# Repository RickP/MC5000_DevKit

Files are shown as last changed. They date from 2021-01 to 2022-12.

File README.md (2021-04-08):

# MC5000_DevKit

A development board that brings the [Shenzhen IO game](https://www.zachtronics.com/shenzhen-io/) to real hardware.

This documentation is intended for people who want to build/extend/bugfix the hardware. 

If you have an MC5000 DevKit board and want to play with it go to the [user documentation](https://rickp.github.io/MC5000_DevKit/).

**I'm planning to order some ready-to-use boards if there are enough people interested. Drop me a message (pannen at gmail dot com) if you're interested in getting one or more**

## Overview

The project consists of three parts. The firmware for the PFS173 microcontroller used in this project, a circuit board that connects to a computer via USB and a cross-platform desktop application that is used to programm the board.

The main use of this is to teach beginners the basics of programming and electronics by solving problems with increasing difficulty. Users have to make electric connection on the circuit board with jumper cable and programm the two microcontrollers with a simplified assembler language to solve the tasks.

## The circuit board

Cuircuit board picture MC5000 DevKit

The board is designed in KiCAD 5, an OpenSource electronics CAD package. In the spirit of the game it is made with the cheapest components I could find. 

The design files are contained in the subfolder 'pcb'. The production files that are needed to make completely assembled boards (Gerbers, Pick&Place, BOM) are compiled automatically and can be found on the [releases page](https://github.com/RickP/MC5000_DevKit/releases) in the zip package "PCB_fabrication_files_for_jlcpcb.zip". 

Currently everything optimized for the chinese board manufacturer [JLCPB](https://jlcpcb.com). Just upload the gerbers (2 layers, 1.6mm PCB), choose "SMT Assembly" and upload the BOM and Pick&Place file when asked for it. For some reason you can have green, black, red or blue boards if you order up to 30 boards. For 50 boards they have to be green or black. If you order 50 boards each one is under 7 Euros including shipping and taxes to the EU (with the 'EuroPackage' shipping option').

Please check if all components are mounted the right way around when ordering. I tried to make sure everything fits but I may not have ordered the latest iteration myself. Also it would be nice it you give me some feedback if you order these. E.g. mention me in a tweet about it (@r1ckp).

## Microcontroller Firmware

The board uses 4 Padauk PFS173 microcontrollers. These are super cheap chinese 8bit microcontrollers that cost about 8cent per piece. They have 3 kilowords of flash ROM and 256 bytes of RAM.

The firmware for the two application controllers (a.k.a. MC5000) and the buzzer and display controller are in the subfolder 'firmware'. They are made with the [Free PDK toolchain](https://free-pdk.github.io) an open-source toolchain for many of the Padauk microcontrollers. It uses the SDCC compiler suite.

The code structure may look a bit weird at first but I had to made some strange constructions to trick the compiler into using as little memory as possible as I was constantly running out of it. **Make sure you use the version 4.1.0 of SDCC as it otimizes the code for the Padauk ICs much better than the 4.0.0 release.**

In order to flash the ICs you have to make or buy an Easy PDK programmer. The programmer is open hardware. I got mine assempled from amazon but you can make one yourself [production files](https://kitspace.org/boards/github.com/free-pdk/easy-pdk-programmer-hardware/). If you want to flash the firmware you need the programmer and the [easy-pdk-programmer software](https://github.com/free-pdk/easy-pdk-programmer-software). 

With the SDCC compiler and easypdkprog in your path just place the breakout boards on the programmer and execute the makefiles:

    cd firmware/MCU5000
    make flash1       # Flash MCU1
    make flash2       # Flash MCU2
    cd ../BUZZER
    make flash        # Flash Buzzer
    cd ../DISPLAY
    make flash        # Flash Display

Firmware binaries can be found on the [releases page](https://github.com/RickP/MC5000_DevKit/releases).

For binary flashing the two MCU5000 ICs have to be flashed with different CPU-IDs:

MCU1: `easypdkprog -s 31 -n PFS173 write MC5000.PFS173.ihx`

MCU2: `easypdkprog -s 32 -n PFS173 write MC5000.PFS173.ihx`

The two peripheral controllers are just flashed without a cpu id:

BUZZER: `easypdkprog -n PFS173 write buzzer.PFS173.ihx`

DISPLAY: `easypdkprog -n PFS173 write display.PFS173.ihx`

## Desktop application

The desktop application parses the code to a binary format and uploads it to the virtual 'MC5000' controllers on the board. It's written in QT5 (Version 5.12.8) and compiled automatically into packages for Linux, MacOS and Windows. Installation instructions are part of the [user documentation](https://rickp.github.io/MC5000_DevKit/).

The code is very simplistic with a lot of room for improvents. It's contained within the 'gui' subdirectory. The binaries can be found on the [releases page](https://github.com/RickP/MC5000_DevKit/releases).

**Currently there's a bug that prevents the rudimantary code error checking for MCU2!**

## Github actions

The releases including binary packages for four platforms and PCB fabrication files are created by a github action (see ".github/workflows/main.yml"). It also signs the MacOS app with my certificate that is stored in github secrets. The built is triggered when the repository is tagged.

If you want the same functionality for the MacOS package on your own fork fork you have to add some secrets in "Project settings/Secrets/Repository secrets":

- APPLE_DEV_USER: Your apple development account user name
- APPLE_DEV_PASS: An application specific password for your apple dev account
- APPLE_DEV_CERT: Your exported developer certificate (including private key) in base64 encoding. Use the same application specific password as above for the cert.

If you don't have an apple developer password you can also remove the signing part from the action. Be aware that this will make the installation of the app for MacOS users much less nice because they will get warnings and have to explicitly allow the execution in the security settings.

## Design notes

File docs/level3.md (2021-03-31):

[home](index) [<< prev level](level2) [next level >>](level4)

# Level 3

Crimedingdong Inc. approached us with an idea for a new home alarm system. They found out that most thiefs use a flashlight when breaking into houses. So they want us to create an alarm system that beeps when it detects light.

## Specification

- Use the "Photontech i5" light sensor to detect the level of light
- When the light level is above 50 sound an alarm with the "Audiomaster Extreme" module
- Stop the alarm when it's getting dark again
- Shine a flashlight (e.g. on your phone) to the light sensor to test your code

## Help

<details markdown=1><summary>Cable connections</summary>
  
- MCU1-P0 -> Light Sensor
- MCU1-X1 -> Buzzer
 
</details>

<details markdown=1><summary>Hints</summary>
  
- Do the development in a darker room
- The "Audiomaster Extreme" beeps with a high tone if you send the number '30' over XBus
- Use the TGT instruction
 
</details>

<details markdown=1><summary>Solution</summary>

MCU1

```
tgt p0 50
+ mov 30 x0
slp 2
```

</details>

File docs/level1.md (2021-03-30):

[home](index) [next level >>](level2)

# Level 1

Blinky Inc. wants us to make a device that blinks a green LED. The CTO told me to let the new guy do it - so it's your job now to do that. Have Fun.

## Specification

- Blink the green LED
- It should be on for about half a second and off for the same time

## Help

<details markdown=1><summary>Cable connections</summary>
  
- MCU1_P0 -> Green LED
 
</details>

<details markdown=1><summary>Hints</summary>
  
- Use the MOV and the SLP instructions
- One unit of sleep is about 100ms
 
</details>

<details markdown=1><summary>Solution</summary>

MCU1

```
mov 100 p0
slp 5
mov 0 p0
slp 5
```

</details>

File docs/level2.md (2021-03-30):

[home](index) [<< prev level](level1) [next level >>](level3)

# Level 2

Our sales guy did not pay attention when talking to Blinky Inc. - they want the LED to blink _only_ if a button is pressed. Please change the code!

## Specification

- Blink the green LED
- It should be on for about half a second and off for the same time
- It should blink only while button 1 is pressed

## Help

<details markdown=1><summary>Cable connections</summary>
  
- MCU1_P0 -> Green LED
- MCU1_P1 -> Button 1
 
</details>

<details markdown=1><summary>Hints</summary>
  
- Use the TEQ instruction
 
</details>

<details markdown=1><summary>Solution</summary>

MCU1

```
teq p1 100
+ mov 100 p0
+ slp 5
+ mov 0 p0
slp 5
```

</details>

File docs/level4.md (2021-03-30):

[home](index) [<< prev level](level3) [next level >>](level5)

# Level 4

Our client Clickybright Co. is making light switches. They found out, that simple tactile buttons are way cheaper than the toggle buttons they are using right now. So they want you to make software that turns the light on with one press and off with anoter one.

## Specification

- Turn on the red LED when pressing button 1
- The LED should turn off with another press of the same button
- It should not matter how long you press the putton

## Help

<details markdown=1><summary>Cable connections</summary>
  
- MCU1_P0 -> Button1
- MCU1_P1 -> Red LED
 
</details>

<details markdown=1><summary>Hints</summary>
  
- Save the information about the last state of the button to a register
- Use the NOT instruction
 
</details>

<details markdown=1><summary>Solution</summary>

MCU1

```
teq p0 100 # check button
- mov 0 dat # not pressed dat=0
+ teq dat 0 # if unpressed before
+ mov 1 dat # mark as pressed
+ not # toggle acc
mov acc p1 # write acc to LED
```

</details>

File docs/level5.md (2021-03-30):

[home](index) [<< prev level](level4) [next level >>](level6)

# Level 5

Clickybright Co. liked your device a lot. Now they want a second product that switches on the light with one button and off with another. So get going!

## Specification

- The red LED should turn on when button 1 is pressed
- It should turn off when button 2 is pressed

## Help

<details markdown=1><summary>Cable connections</summary>
  
- MCU1_P0 -> Button_1
- MCU1_P1 -> Button_2
- MCU1_X0 -> MCU2_X0
- MCU2_P0 -> Red LED
 
</details>

<details markdown=1><summary>Hints</summary>
  
- Use both MC5000 controllers
 
</details>

<details markdown=1><summary>Solution</summary>

MCU1

```
teq p0 100
- mov 0 dat
+ teq dat 0 
+ mov 1 dat
+ mov 100 x0
teq p1 100
- mov 0 dat
+ teq dat 0 
+ mov 1 dat
+ mov 0 x0
```

MCU2

```
mov x0 p0
```

</details>

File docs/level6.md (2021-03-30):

[home](index) [<< prev level](level5) To be continued...

# Level 6

The customer TrafficControl Inc. wants you to create a new control mechanism for their pedestrian traffic lights.

## Specification

- On start the traffic light needs to be red.
- When a pedestrian presses a button a display shall count down from 10 to 0
- When the timer reaches zero the traffic light goes from red to red-yellow to green
- After some seconds the traffic light goes back to yellow and then to red 

## Help

<details markdown=1><summary>Cable connections</summary>
  
- MCU1-P0 -> Button1
- MCU1-P1 -> Red LED
- MCU1-X0 -> Display
- MCU1-X1 -> MCU2-X0
- MCU1-P0 -> Green LED
- MCU1-P1 -> Yellow LED
 
</details>

<details markdown=1><summary>Hints</summary>
  
- MCU2 should control the green and yellow LEDs when MCU1 sends an XBus signal
- MCU1 displays the countdown in a loop and then sends the signal to MCU2
- After sending the signal MCU1 waits for an XBus signal from MCU2 to switch back to red
 
</details>

<details markdown=1><summary>Solution</summary>

MCU1

```
start:
mov 100 p1
teq p0 100
- jmp start
mov 10 acc
loop:
sub 1
mov acc x0
slp 4
tgt acc 0
+ jmp loop
mov 1 x1
slp 4
mov 0 p1
mov x1 dat
```

MCU2

```
teq x0 1
+ mov 100 p1
+ slp 5
+ mov 0 p1
+ mov 100 p0
+ slp 30
+ mov 0 p0
+ mov 100 p1
+ slp 5
+ mov 0 p1
+ mov 0 x0
```

</details>

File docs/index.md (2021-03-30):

You need a circuit board like this to play:

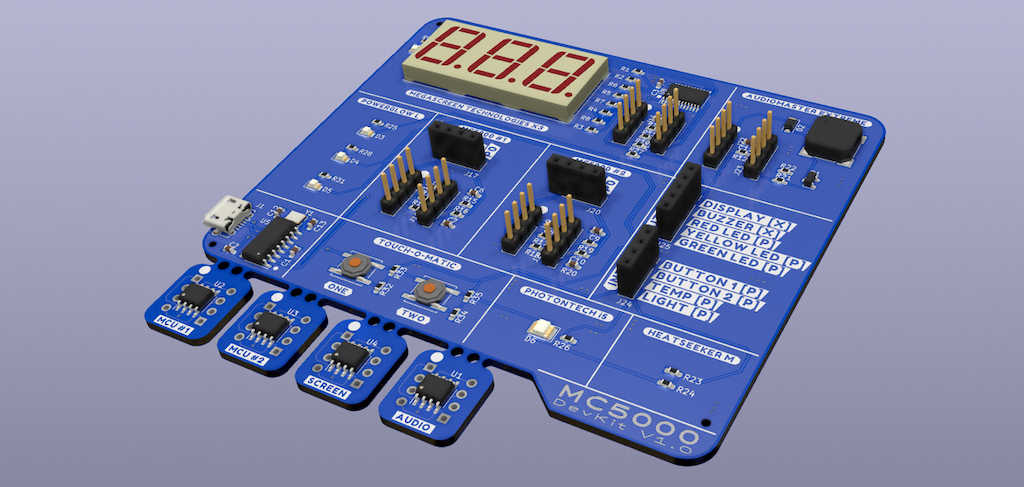
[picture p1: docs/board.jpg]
Circuit board picture


## Intructions

[Installing the desktop app](install)

[Making connections on the board](connections)

[The assembler language](assembler)

## Levels

[Level 1](level1)

[Level 2](level2)

[Level 3](level3)

[Level 4](level4)

[Level 5](level5)

[Level 6](level6)

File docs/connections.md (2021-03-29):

[<< back](index)

# Making connections

## Ports

The MC5000 DevKit has 2 different types of ports (or pins) that can be connected. Simple I/O and XBus.
The 2 MC5000 controllers in the middle have each 2 XBus ports (X0 and X1) and 2 Simple I/O ports (P0 and P1).
They can all be used as data inputs or data outputs.

- A Simple I/O port can be set or read from at any time. The value of a Simple I/O port can be set to a value between 0 and 100.
- The XBus port can only be written to if another XBus port is listening to it. It can be set to value between -999 and 999.

The "Megascreen Technologies X3" display and the "Audiomaster Extreme" are XBus input devices. They are always listening. 
The other inputs and outputs are Simple I/O devices. You use the supplied jumper cables to connect the ports.

__Only connect Simple I/O to Simple I/O and XBus to XBus ports!__

## Try it out

Connect the DevKit to yout computer via USB. Connect the "RED LED" output to the "Button 1" input. 
If you press "Button 1" the red LED lights up. Try it with the other button and the other LEDs.

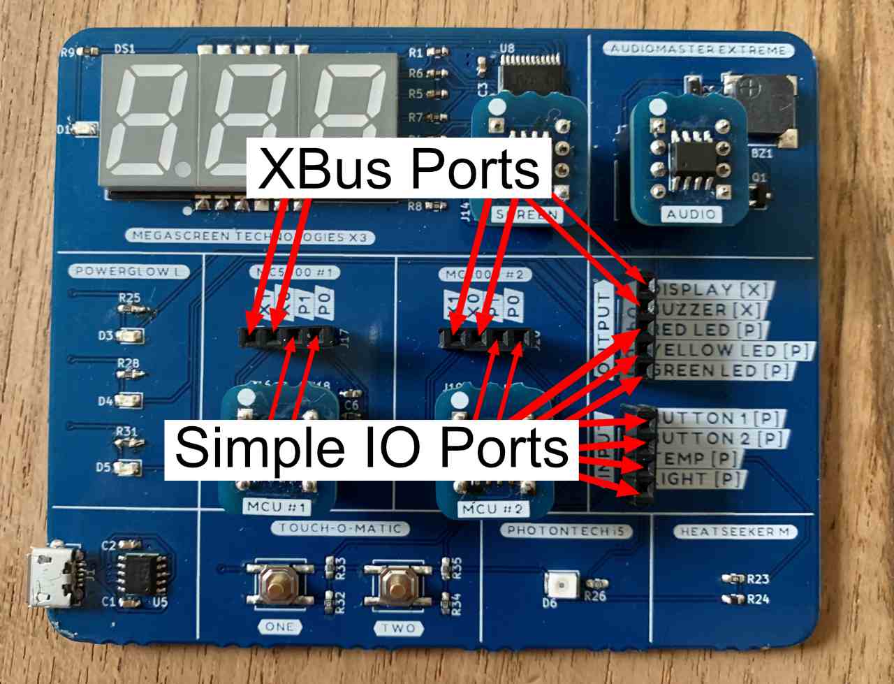
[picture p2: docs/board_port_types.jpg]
Port markings on board


Now it's time to write some [assembler code](assembler)

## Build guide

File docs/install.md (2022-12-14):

[<< back](index)

# Install the desktop app

Go to the [release page](https://github.com/RickP/MC5000_DevKit/releases), click on "Assets" on the topmost release and download the latest package for your platform (the files starting with "MC5000-GUI").

See specific instruction for your operating system below.

## Linux

There are AppImge packages for 64bit Intel systems (x86_64) and 64bit ARM (arm64). If you have a Raspberry Pi use the Arm64 one. You need the 64 bit Raspian installed on a Pi3 or Pi4 from [here](http://downloads.raspberrypi.org/raspios_arm64/images/).

The AppImage needs to be made executable after download. [This](https://docs.appimage.org/introduction/quickstart.html#ref-quickstart) explains how to do it.

The App should run on any recent Linux (Ubuntu 18.04 and up) without any drivers. If the board is not recognized as an usb-to-serial device install the driver from [here](http://www.wch-ic.com/search?q=CH340&t=downloads)

## MacOS

Just download the dmg and move the app to your Applications directory. Click on it to start. MacOS Catalina and up have the USB driver included. It's intel only but runs just fine on an M1 Mac.

If the board is not recognized as an usb-to-serial device install the driver from [here](http://www.wch-ic.com/search?q=CH340&t=downloads)

## Windows

Download the zip file and unpack it to your disk. 

Unfortunately you have to install drivers for the USB->Serial chip on windows. Get them from [here](http://www.wch-ic.com/search?q=CH340&t=downloads) and install them. Then connect the board via USB and run the MC5000.exe in the folder. 

You may have to install the C++ runtime "vc_redist.x64.exe" in the application folder if windows complains about something missing - but chances are high that you already have this.

# Usage

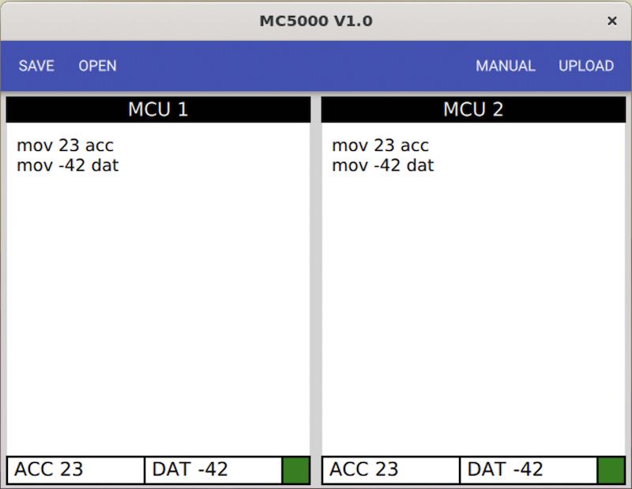
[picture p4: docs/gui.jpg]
GUI screenshot


When the app opens up you may have to choose the correct USB port. If you're not sure unplug the board, click refresh, plug it in, click refresh and choose the one that was added to the list.

The user interface is pretty simple. You can load and save code to a text file. The button "Manual" is a link to this documentation. "Upload" writes the code you entered to the board.

Now [connect some wires](connections)

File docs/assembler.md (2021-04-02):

[<< back](index)

# The assembler language

## Program Structure

Each line of an MC5000 program must have the following structure:

    LABEL CONDITION INSTRUCTION COMMENT

All components are optional, but must appear in the specified order if present. 
Examples of syntactically valid lines:

```
# This line is a comment. 
loop: # until ACC is ten
teq acc 10 
+ jmp end
mov 50 x2 
add 1 
jmp loop
end:
mov 0 acc # reset counter
```

## Comments

Any text following a “#” symbol is ignored until the end of the line. Comments improve developer productivity by allowing the behavior of code to be described in-line with the program itself.

## Labels

Labels must appear first on a line, and are followed by a colon (“__:__”). Labels are used as jump targets by the __jmp__ instruction. Labels must begin with a letter and may contain alphabetic, numeric, and underscore characters.

## Conditional Execution

All instructions in the MC5000 programming language are capable of conditional execution. 

Prefixing an instruction with a “__+__” or “__-__” symbol will cause that instruction to be enabled or disabled by test instructions. 

When an instruction is disabled by a test instruction, it will be skipped and will not consume power. Instructions with no prefix are never disabled and always execute normally. All conditional instructions start in a disabled state. A test instruction must be executed to enable conditional instructions.

## Registers

Registers are used as sources and destinations for data manipulated by MC5000 instructions.

__acc__ is the primary general-purpose register used for internal computation on MC5000 microcontrollers. All arithmetic operations implicitly use and modify the value of __acc__.

__dat__ is a second register available on the MC5000. It can be used in most contexts where __acc__ is permitted.

The internal registers of the MC5000 microprocessor (__acc__ and __dat__) are initialized to the value 0.
The pin registers (__p0__, __p1__, __x0__, __x1__) are used when reading from or writing to the pins of MC5000 microcontrollers. Reading and writing through the pins allows a single MC5000 microcontroller to communicate and coordinate with other connected, compatible devices. Each pin on an MC5000 microcontroller functions as either a simple I/O or XBus interface.

## Instruction Operands

Each type of instruction requires a fixed number of operands. If an instruction has any associated operands, they must appear following the instruction name, separated by spaces. For the benefit of development productivity, the MC5000 programming system does not require the use of redundant punctuation to separate instruction operands.

Instruction operands are described with the following notation:

| Notation | Meaning |
|:---:|:---:|
| R | Register |
| I | Integer [1] |
| R/I | Register or integer [1] |
| P | Pin register (p0, p1, etc.) |
| L | Label [2] |

[1] Integer values must be in the range -999 to 999.

[2] Labels used as operands must be defined elsewhere in the program.

## Basic Instructions

__mov R/I R__ : Copy the value of the first operand into the second operand.

__jmp L__ : Jump to the instruction following the specified label.

__slp R/I__ : Sleep for the number of time units specified by the operand.

__slx P__ : Sleep until data is available to be read on the XBus pin specified by the operand.

## Arithmetic Instructions

Registers can store integer values between -999 and 999, inclusive. If an arithmetic operation would produce a result outside this range, the closest allowed value is stored instead. For example, if acc contains the value 800 and the instruction add 400 is executed, then the value 999 will be stored in acc.

__add R/I__ : Add the value of the first operand to the value of the acc register and store the result in the acc register.

__sub R/I__ : Subtract the value of the first operand from the value of the acc register and store the result in the acc register.

__mul R/I__  : Multiply the value of the first operand by the value of the acc register and store the result in the acc register.

__not__ : If the value in acc is 0, store a value of 100 in acc. Otherwise, store a value of 0 in acc. 

__dgt R/I__ : Isolate the specified digit of the value in the acc register and store the result in the acc register. 

__dst R/I R/I__ : Set the digit of acc specified by the first operand to the value of the second operand. Examples of the dgt and dst instructions:

| acc  | Instruction | acc’ |
|:----:|:---:|:----:|
| 596  | dgt 0 | 6 |
| 596  | dgt 1 | 9 |
| 596  | dgt 2 | 5 |
| 596  | dst 0 7 | 597  |
| 596  | dst 1 7 | 576  |
| 596  | dst 2 7 | 796  |

## Test Instructions

__teq R/I R/I__ : Test if the value of the first operand (A) is equal to the value of the second operand (B).

| Condition | Effect on ‘+’ Instructions | Effect on ‘-’ Instructions’ |
|:---:|:---:|:---:|
| A is equal to B | Enabled | *Disabled* |
| A is not equal to B  | *Disabled* | Enabled |

__tgt R/I R/I__ : Test if the value of the first operand (A) is greater than the value of the second operand (B).

| Condition | Effect on ‘+’ Instructions | Effect on ‘-’ Instructions’ |
|:---:|:---:|:---:|
| A is greater than B | Enabled | *Disabled* |
| A is not greater than B | *Disabled* | Enabled |

__tlt R/I R/I__ : Test if the value of the first operand (A) is less than the value of the second operand (B).

| Condition | Effect on ‘+’ Instructions | Effect on ‘-’ Instructions’ |
|:---:|:---:|:---:|
| A is less than B | Enabled | *Disabled* |
| A is not less than B | *Disabled* | Enabled |

__tcp R/I R/I__ : Compare the value of the first operand (A) to the value of the second operand (B).

| Condition | Effect on ‘+’ Instructions | Effect on ‘-’ Instructions’ |
|:---:|:---:|:---:|
| A is greater than B  | Enabled | *Disabled* |
| A is equal to B | *Disabled* | *Disabled* |
| A is less than B | *Disabled* | Enabled |

Now you should be able to solve your first [task](level1)

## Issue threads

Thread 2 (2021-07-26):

PFS173 hard to obtain

james-coder, 2021-07-26:
I think this project would be really cool to use/build. I went to JLCPCB's LCSC inventory for the PFS173 and found it's zero. (In fact, all Padauk's chips are zero.) I've reached out to Padauk and they just responded to me. They basically said those chips are still in production. The literal response from them was: "Because the wafers supply is not good enough and I think it is the reason why LCSC has no stocks." (Not 100% sure what that means. Maybe just a shortage of materials?) Interestingly, I see that the PFS173 is available from: Taobao, Alibaba, and Aliexpress. If worst came to worst, I'd just go to one of these places. But - this would be 100% easier if it was on JLCPCB's pick and place inventory so I have to do less solder work. I've contacted LCSC and asked them why the PFS173 inventory is at zero. (Going through Aliexpress would mean it's at around $0.41/chip instead of a few pennies. Probably not a problem, I've probably already put more time and effort into researching down this chip, and there is this code repo that already is specialized towards the PFS173.) Hoping to be able to build this one day.

RickP, 2022-03-02:
6 months later and still no stock :( - I'd used something else if I would have known this before. Hope it resolves when the chip crisis is over someday - I guess they're using all fabs and material to make higher end chips.

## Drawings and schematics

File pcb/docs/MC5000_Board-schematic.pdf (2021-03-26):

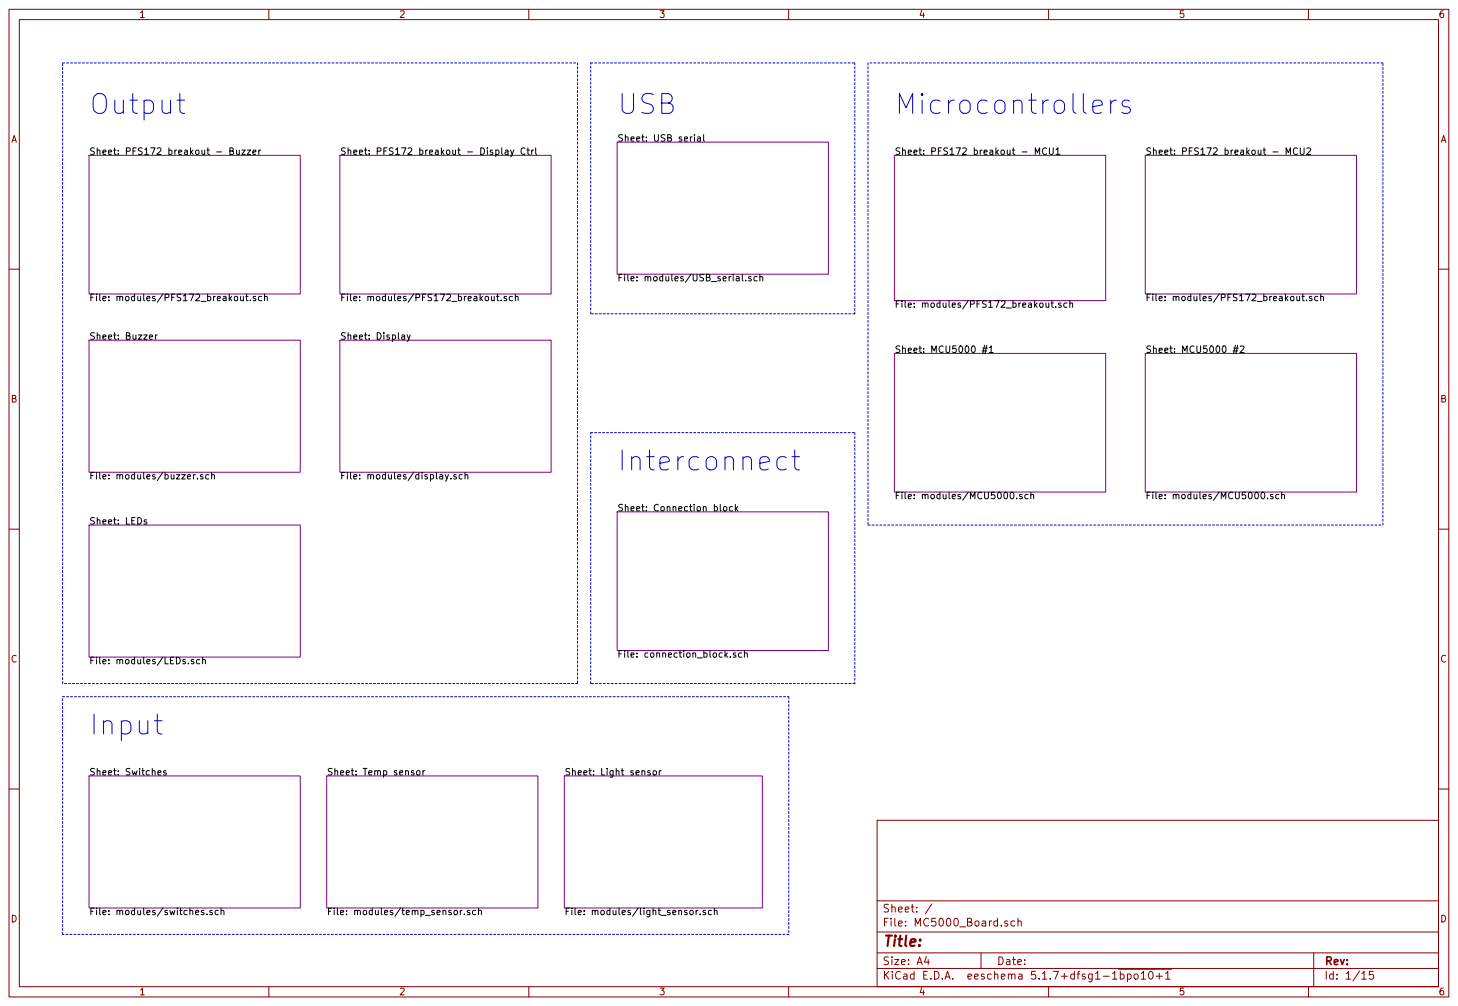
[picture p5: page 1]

File: modules/temp_sensor.sch Sheet: Switches File: modules/switches.sch

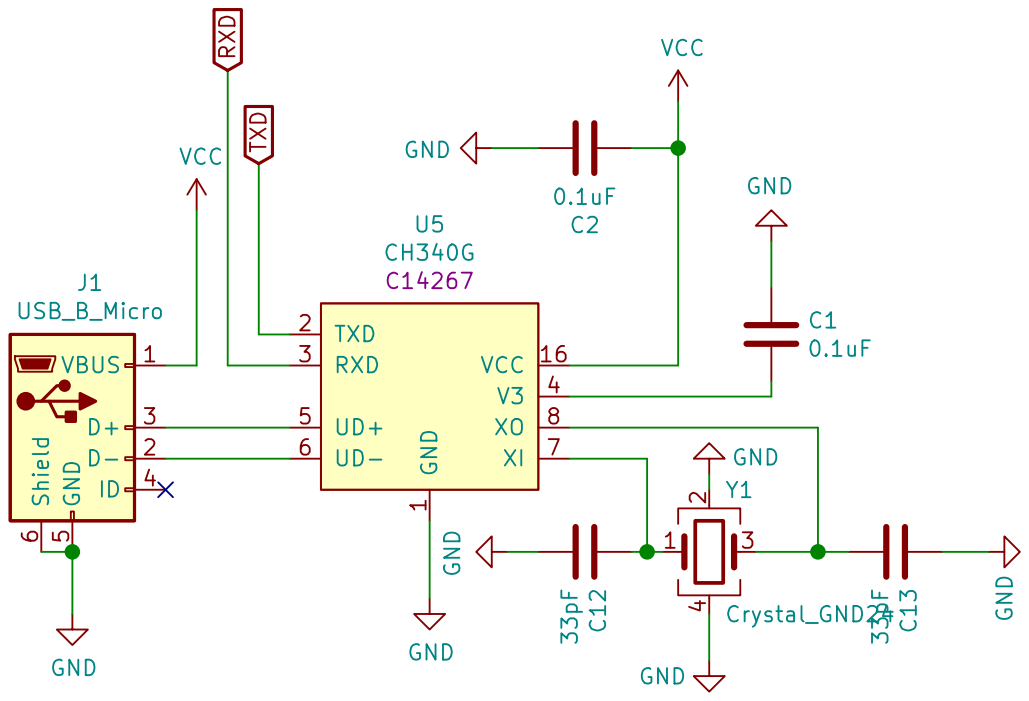
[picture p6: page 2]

File: USB_serial.sch Sheet: /USB serial/ GND GND
0.1uF GND

1 VCC 16 TXD 2 RXD 3 V3 4 UD+ 5 UD- 6 XI 7 XO 8 U5 CH340G

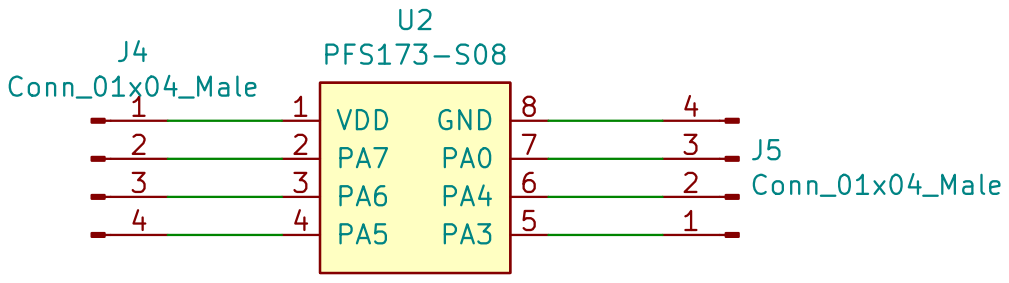
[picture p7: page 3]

File: PFS172_breakout.sch Sheet: /PFS172 breakout - MCU1/
Id: 3/15 Title:

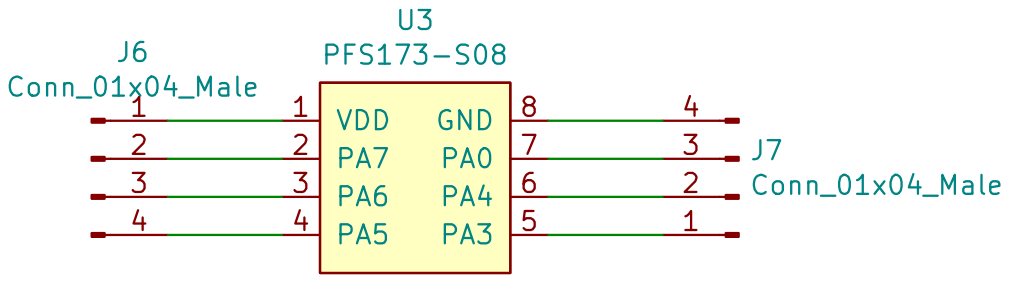
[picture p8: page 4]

File: PFS172_breakout.sch Sheet: /PFS172 breakout - MCU2/
Id: 4/15 Title:

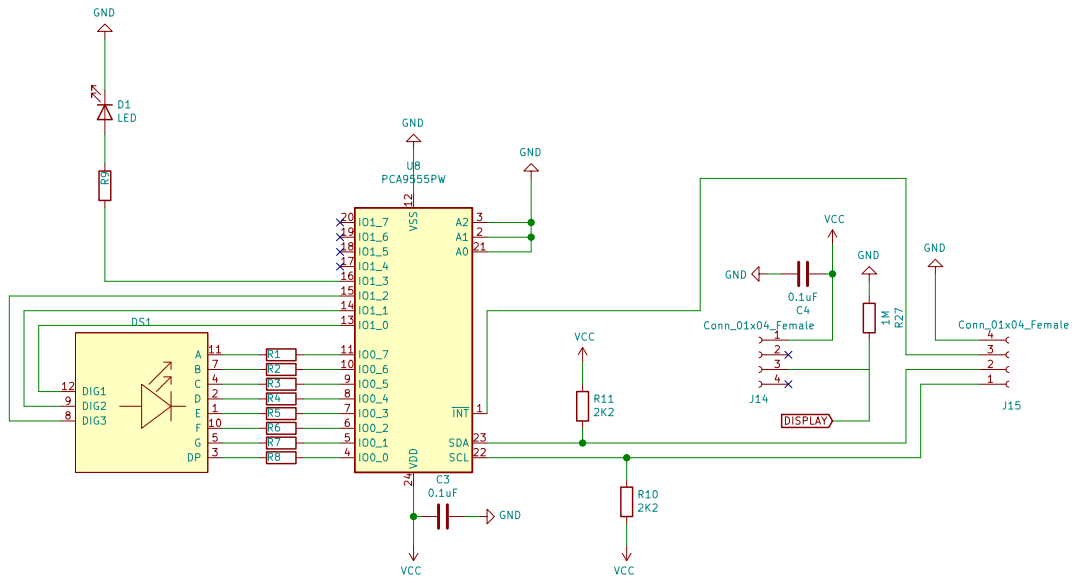
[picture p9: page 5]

IO1_1 14
IO1_0 13

D | 11 DIG1 12 10 A 5 B 4 G 2 DP 3 C 1 F

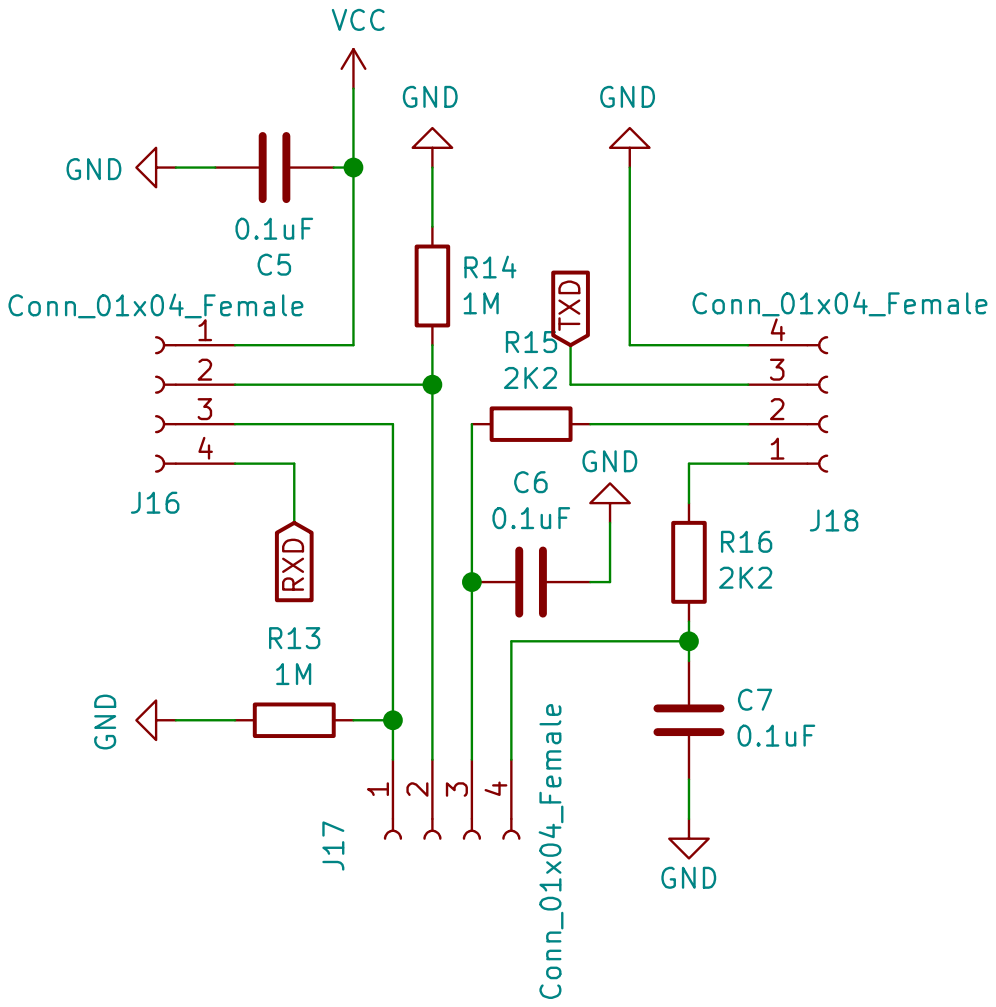
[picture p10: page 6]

Id: 6/15 Title: File: MCU5000.sch Sheet: /MCU5000 #1/ GND GND

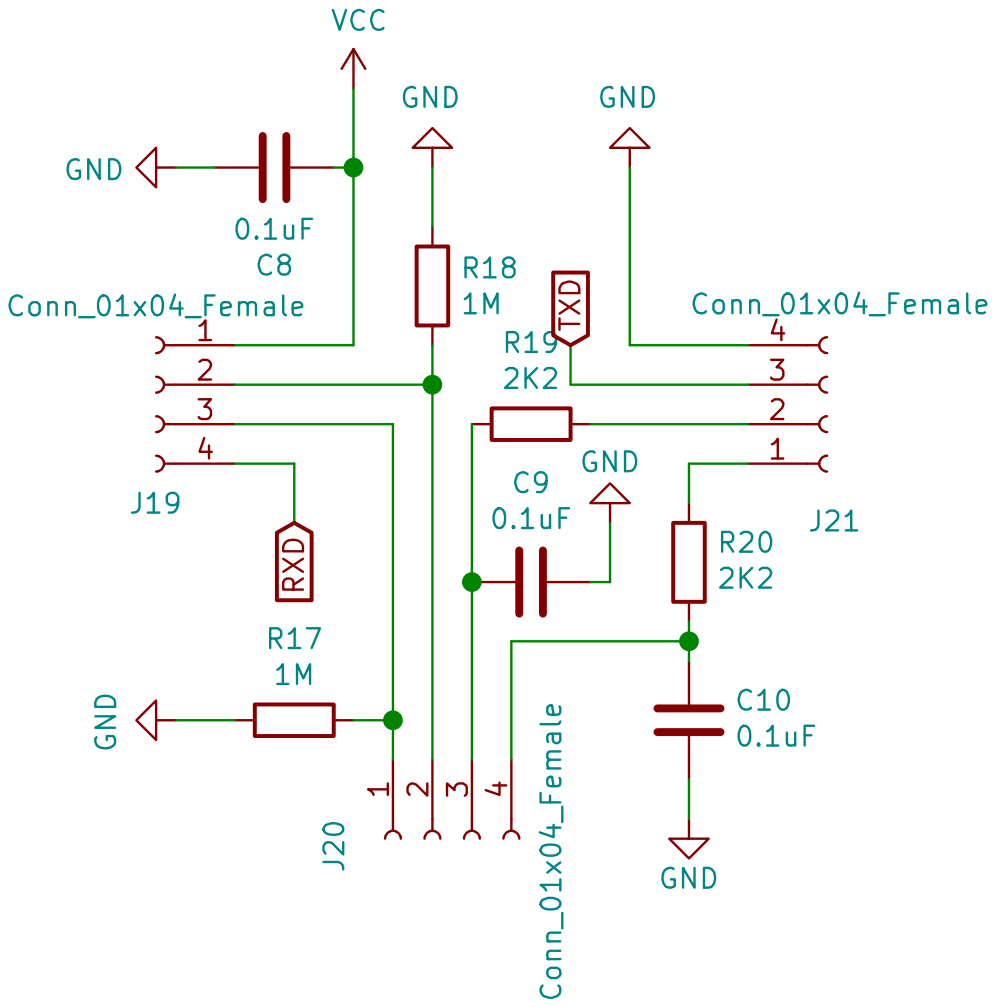
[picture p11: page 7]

Id: 7/15 Title: File: MCU5000.sch Sheet: /MCU5000 #2/ GND GND

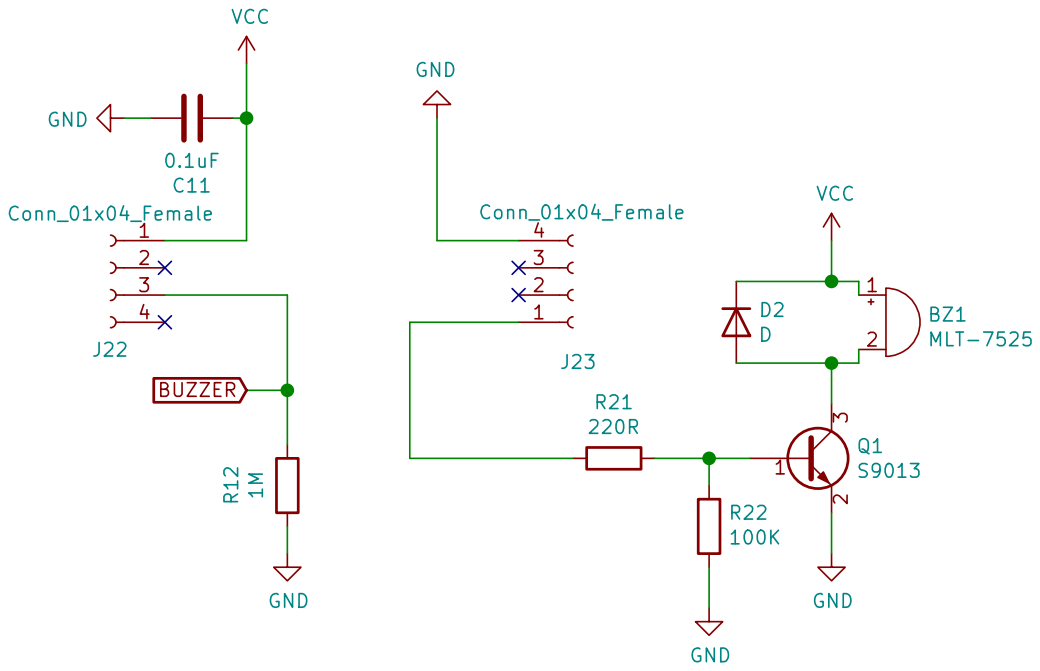
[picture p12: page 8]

Id: 8/15 Title: File: buzzer.sch Sheet: /Buzzer/

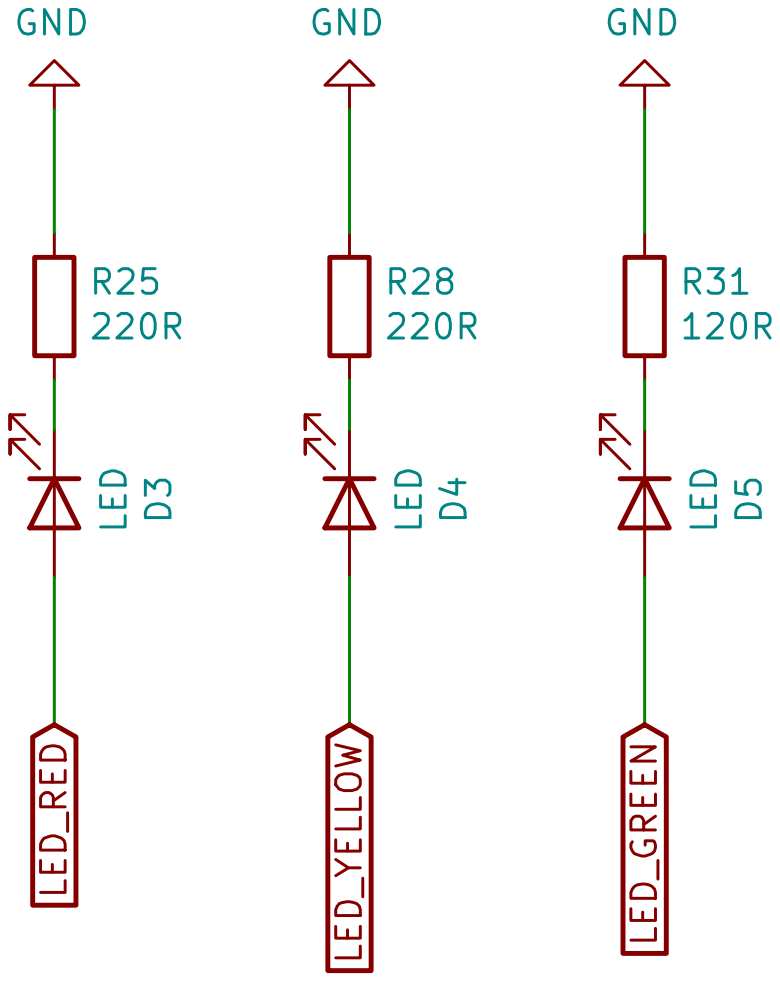
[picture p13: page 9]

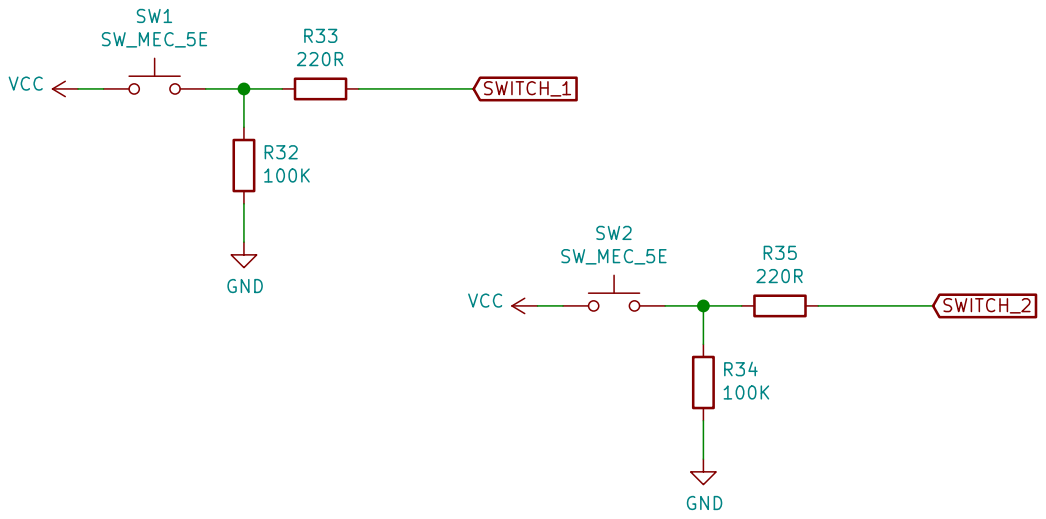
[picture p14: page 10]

Id: 10/15 Title: File: switches.sch Sheet: /Switches/

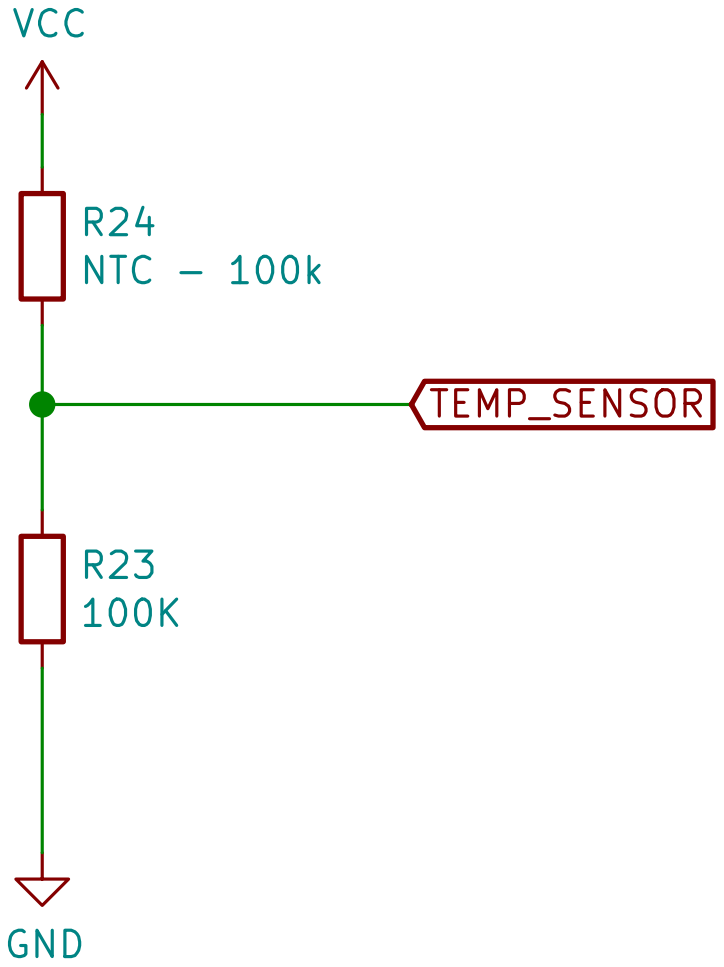
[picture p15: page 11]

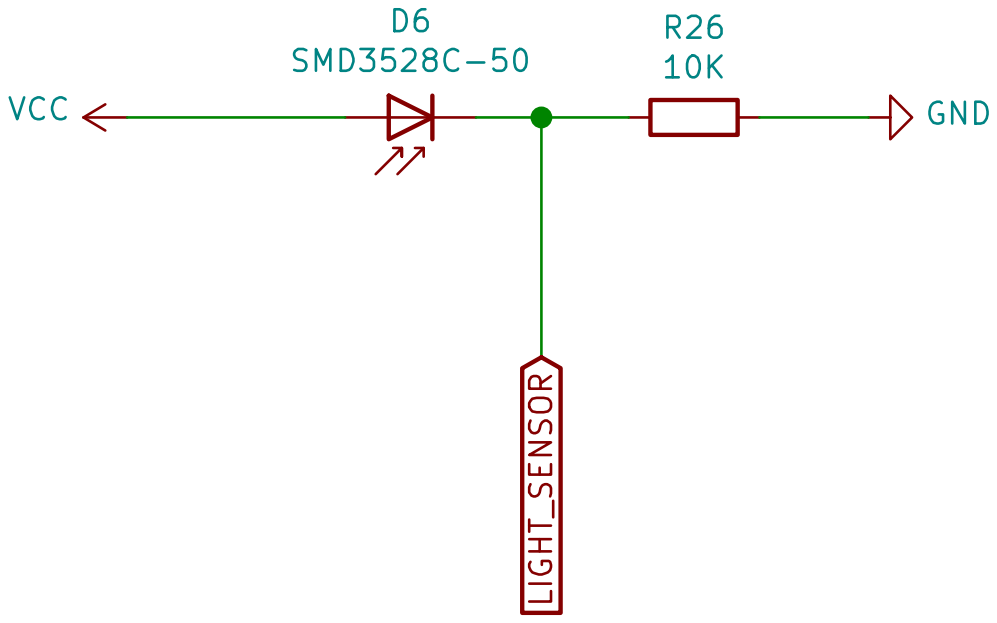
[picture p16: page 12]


File: connection_block.sch Sheet: /Connection block/
Id: 13/15 Title:


Sheet: /PFS172 breakout - Display Ctrl/
File: PFS172_breakout.sch
Id: 14/15 Title:


File: PFS172_breakout.sch Sheet: /PFS172 breakout - Buzzer/
Id: 15/15 Title:


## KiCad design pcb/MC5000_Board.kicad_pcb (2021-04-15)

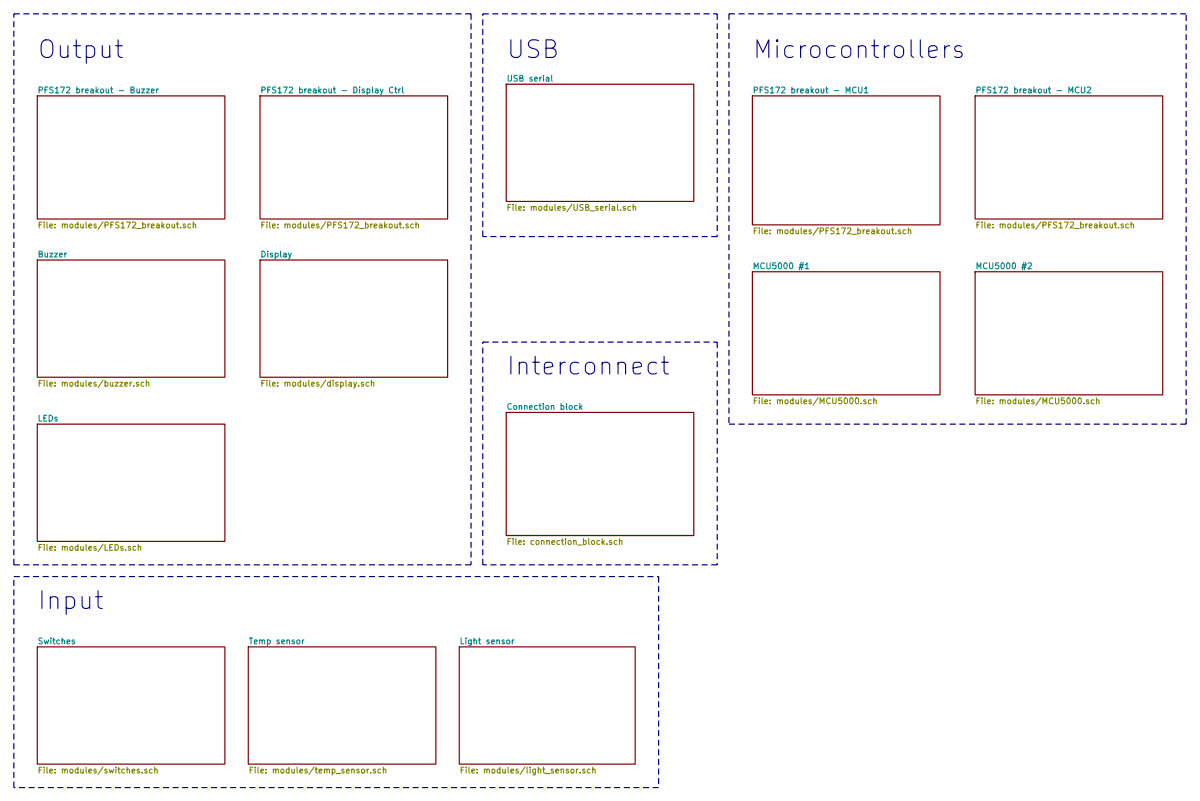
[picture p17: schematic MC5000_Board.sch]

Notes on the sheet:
Microcontrollers
Interconnect
USB
Output
Input

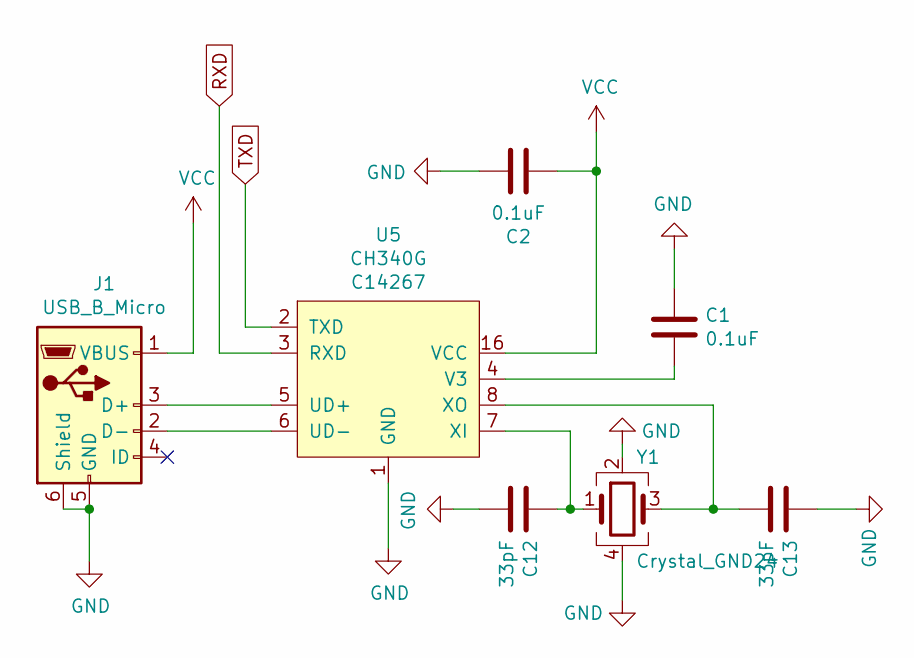
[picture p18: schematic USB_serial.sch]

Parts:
C1, C2: 0.1uF; C_0603_1608Metric_Pad1.08x0.95mm_HandSolder; LCSC C14663
C12, C13: 33pF; C_0603_1608Metric_Pad1.08x0.95mm_HandSolder; LCSC C1663
J1: USB_B_Micro; MicroXNJ; LCSC C404969
U5: CH340G; SOP-16_3.9x9.9mm_P1.27mm_rotated; LCSC C14267
Y1: Crystal_GND24; Crystal_SMD_3225-4Pin_3.2x2.5mm; LCSC C9002

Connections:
GND: C1.1, C2.1, C12.2, C13.1, J1.5 (GND), J1.6 (Shield), U5.1 (GND), Y1.2, Y1.4; also elsewhere on the board
unnamed: C1.2, U5.4 (V3)
unnamed: C12.1, U5.7 (XI), Y1.1
unnamed: C13.2, U5.8 (XO), Y1.3
unnamed: J1.2 (D-), U5.6 (UD-)
unnamed: J1.3 (D+), U5.5 (UD+)
RXD: U5.3 (RXD); also elsewhere on the board
TXD: U5.2 (TXD); also elsewhere on the board
VCC: C2.2, J1.1 (VBUS), U5.16 (VCC); also elsewhere on the board

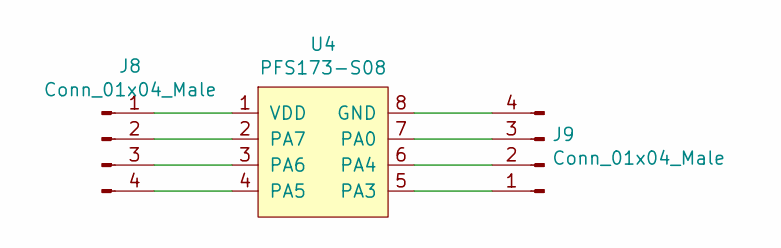
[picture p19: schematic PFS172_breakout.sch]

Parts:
J2, J3: Conn_01x04_Male; PinHeader_1x04_P2.54mm_plug; LCSC C124378
U1: PFS173-S08; SOP-8_3.9x4.9mm_P1.27mm_rotated; LCSC C337970

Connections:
unnamed: J2.1, U1.1 (VDD)
unnamed: J2.2, U1.2 (PA7)
unnamed: J2.3, U1.3 (PA6)
unnamed: J2.4, U1.4 (PA5)
unnamed: J3.1, U1.5 (PA3)
unnamed: J3.2, U1.6 (PA4)
unnamed: J3.3, U1.7 (PA0)
unnamed: J3.4, U1.8 (GND)

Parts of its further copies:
J4, J5, J6, J7, J8, J9, J10, J11, J12, J13: Conn_01x04_Male; PinHeader_1x04_P2.54mm_plug; LCSC C124378
U2, U3, U4, U6, U7: PFS173-S08; SOP-8_3.9x4.9mm_P1.27mm_rotated; LCSC C337970

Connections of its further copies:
unnamed: J4.1, U2.1 (VDD)
unnamed: J4.2, U2.2 (PA7)
unnamed: J4.3, U2.3 (PA6)
unnamed: J4.4, U2.4 (PA5)
unnamed: J5.1, U2.5 (PA3)
unnamed: J5.2, U2.6 (PA4)
unnamed: J5.3, U2.7 (PA0)
unnamed: J5.4, U2.8 (GND)
unnamed: J6.1, U3.1 (VDD)
unnamed: J6.2, U3.2 (PA7)
unnamed: J6.3, U3.3 (PA6)
unnamed: J6.4, U3.4 (PA5)
unnamed: J7.1, U3.5 (PA3)
unnamed: J7.2, U3.6 (PA4)
unnamed: J7.3, U3.7 (PA0)
unnamed: J7.4, U3.8 (GND)
unnamed: J8.1, U4.1 (VDD)
unnamed: J8.2, U4.2 (PA7)
unnamed: J8.3, U4.3 (PA6)
unnamed: J8.4, U4.4 (PA5)
unnamed: J9.1, U4.5 (PA3)
unnamed: J9.2, U4.6 (PA4)
unnamed: J9.3, U4.7 (PA0)
unnamed: J9.4, U4.8 (GND)

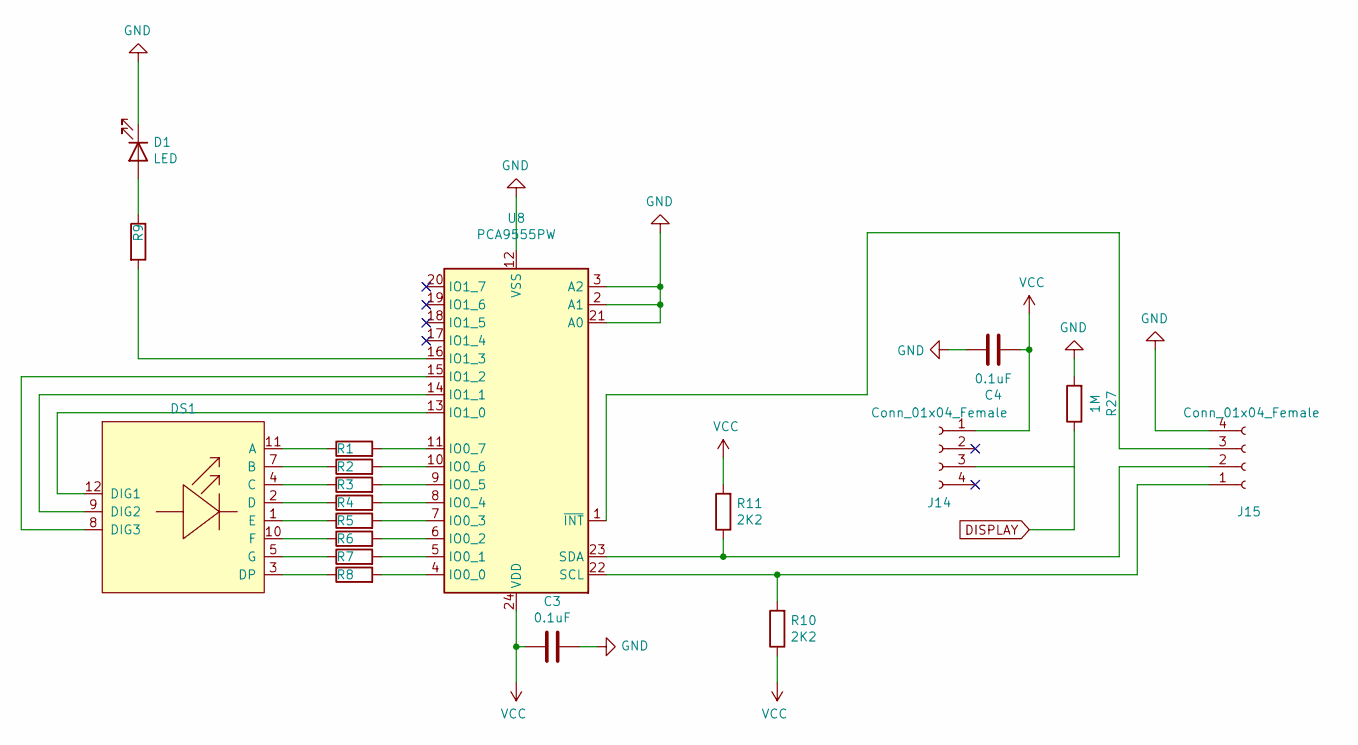
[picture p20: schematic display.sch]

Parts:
C3, C4: 0.1uF; C_0603_1608Metric_Pad1.08x0.95mm_HandSolder; LCSC C14663
D1: LED; LED_0805_2012Metric_Pad1.15x1.40mm_HandSolder; LCSC C2297
DS1: SLR0523DYA1BD; LCSC C225932
J14, J15: Conn_01x04_Female; PinHeader_1x04_P2.54mm_Vertical_centered; LCSC C124378
R1, R2, R3, R4, R5, R6, R7, R8: 220R; R_0603_1608Metric_Pad0.98x0.95mm_HandSolder; LCSC C22962
R9, R10, R11: 2K2; R_0603_1608Metric_Pad0.98x0.95mm_HandSolder; LCSC C4190
R27: 1M; R_0603_1608Metric_Pad0.98x0.95mm_HandSolder; LCSC C22935
U8: PCA9555PW; TSSOP-24_4.4x7.8mm_P0.65mm_rotated; LCSC C128392

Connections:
DISPLAY: J14.3, R27.1; also elsewhere on the board
GND: C3.1, C4.1, D1.1 (K), J15.4, R27.2, U8.2 (A1), U8.3 (A2), U8.12 (VSS), U8.21 (A0); also elsewhere on the board
unnamed: D1.2 (A), R9.1
unnamed: DS1.1 (E), R5.1
unnamed: DS1.2 (D), R4.1
unnamed: DS1.3 (DP), R8.1
unnamed: DS1.4 (C), R3.1
unnamed: DS1.5 (G), R7.1
unnamed: DS1.7 (B), R2.1
unnamed: DS1.8 (DIG3), U8.15 (IO1_2)
unnamed: DS1.9 (DIG2), U8.14 (IO1_1)
unnamed: DS1.10 (F), R6.1
unnamed: DS1.11 (A), R1.1
unnamed: DS1.12 (DIG1), U8.13 (IO1_0)
unnamed: J15.1, R10.2, U8.22 (SCL)
unnamed: J15.2, R11.1, U8.23 (SDA)
unnamed 69: J15.3, U8.1 (~INT); also elsewhere on the board
unnamed: R1.2, U8.11 (IO0_7)
unnamed: R2.2, U8.10 (IO0_6)
unnamed: R3.2, U8.9 (IO0_5)
unnamed: R4.2, U8.8 (IO0_4)
unnamed: R5.2, U8.7 (IO0_3)
unnamed: R6.2, U8.6 (IO0_2)
unnamed: R7.2, U8.5 (IO0_1)
unnamed: R8.2, U8.4 (IO0_0)
unnamed: R9.2, U8.16 (IO1_3)
VCC: C3.2, C4.2, J14.1, R10.1, R11.2, U8.24 (VDD); also elsewhere on the board

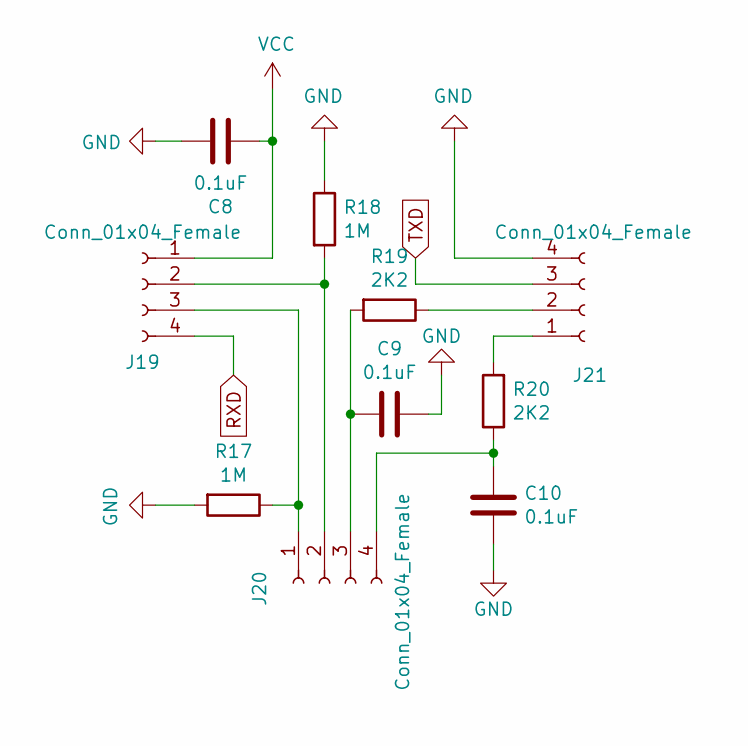
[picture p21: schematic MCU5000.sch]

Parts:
C5, C6, C7: 0.1uF; C_0603_1608Metric_Pad1.08x0.95mm_HandSolder; LCSC C14663
J16, J18: Conn_01x04_Female; PinHeader_1x04_P2.54mm_Vertical_centered; LCSC C124378
J17: Conn_01x04_Female; PinSocket_1x04_P2.54mm_Vertical_centered; LCSC C124413
R13, R14: 1M; R_0603_1608Metric_Pad0.98x0.95mm_HandSolder; LCSC C22935
R15, R16: 2K2; R_0603_1608Metric_Pad0.98x0.95mm_HandSolder; LCSC C4190

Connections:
GND: C5.1, C6.1, C7.1, J18.4, R13.2, R14.1; also elsewhere on the board
unnamed: C6.2, J17.3, R15.2
unnamed: C7.2, J17.4, R16.1
unnamed: J16.2, J17.2, R14.2
unnamed: J16.3, J17.1, R13.1
unnamed: J18.1, R16.2
unnamed: J18.2, R15.1
RXD: J16.4; also elsewhere on the board
TXD: J18.3; also elsewhere on the board
VCC: C5.2, J16.1; also elsewhere on the board

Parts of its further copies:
C8, C9, C10: 0.1uF; C_0603_1608Metric_Pad1.08x0.95mm_HandSolder; LCSC C14663
J19, J21: Conn_01x04_Female; PinHeader_1x04_P2.54mm_Vertical_centered; LCSC C124378
J20: Conn_01x04_Female; PinSocket_1x04_P2.54mm_Vertical_centered; LCSC C124413
R17, R18: 1M; R_0603_1608Metric_Pad0.98x0.95mm_HandSolder; LCSC C22935
R19, R20: 2K2; R_0603_1608Metric_Pad0.98x0.95mm_HandSolder; LCSC C4190

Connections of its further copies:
GND: C8.1, C9.1, C10.1, J21.4, R17.2, R18.1; also elsewhere on the board
unnamed: C9.2, J20.3, R19.2
unnamed: C10.2, J20.4, R20.1
unnamed: J19.2, J20.2, R18.2
unnamed: J19.3, J20.1, R17.1
unnamed: J21.1, R20.2
unnamed: J21.2, R19.1
RXD: J19.4; also elsewhere on the board
TXD: J21.3; also elsewhere on the board
VCC: C8.2, J19.1; also elsewhere on the board

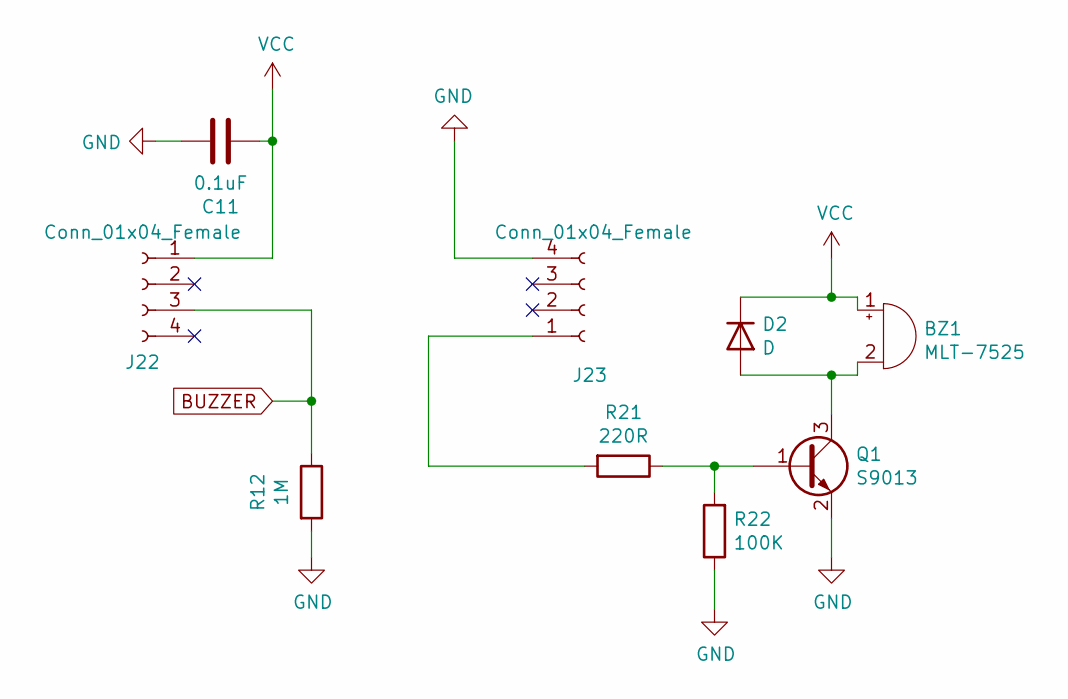
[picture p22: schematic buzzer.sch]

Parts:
BZ1: MLT-7525; MagneticBuzzer_7.5x7.5_SMT; LCSC C95299
C11: 0.1uF; C_0603_1608Metric_Pad1.08x0.95mm_HandSolder; LCSC C14663
D2: D; D_SOD-123F; LCSC C64898
J22, J23: Conn_01x04_Female; PinHeader_1x04_P2.54mm_Vertical_centered; LCSC C124378
Q1: S9013; SOT-23_rotated; LCSC C6749
R12: 1M; R_0603_1608Metric_Pad0.98x0.95mm_HandSolder; LCSC C22935
R21: 220R; R_0603_1608Metric_Pad0.98x0.95mm_HandSolder; LCSC C22962
R22: 100K; R_0603_1608Metric_Pad0.98x0.95mm_HandSolder; LCSC C25803

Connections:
BUZZER: J22.3, R12.1; also elsewhere on the board
GND: C11.1, J23.4, Q1.2 (E), R12.2, R22.1; also elsewhere on the board
unnamed: BZ1.2 (+), D2.2 (A), Q1.3 (C)
unnamed: J23.1, R21.2
unnamed: Q1.1 (B), R21.1, R22.2
VCC: BZ1.1 (-), C11.2, D2.1 (K), J22.1; also elsewhere on the board

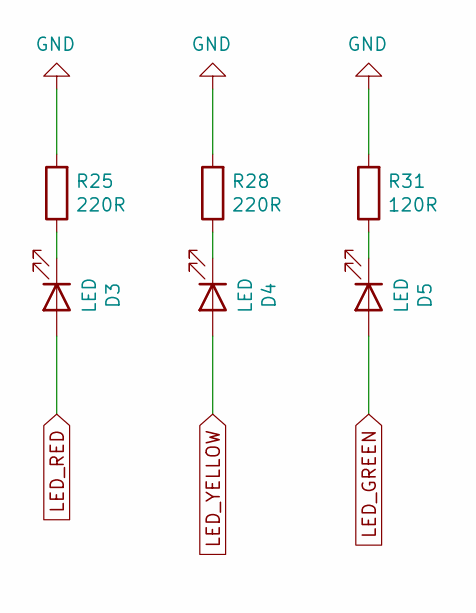
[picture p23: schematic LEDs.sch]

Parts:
D3: LED; LED_0805_2012Metric_Pad1.15x1.40mm_HandSolder; LCSC C84256
D4: LED; LED_0805_2012Metric_Pad1.15x1.40mm_HandSolder; LCSC C2296
D5: LED; LED_0805_2012Metric_Pad1.15x1.40mm_HandSolder; LCSC C2297
R25, R28: 220R; R_0603_1608Metric_Pad0.98x0.95mm_HandSolder; LCSC C22962
R31: 120R; R_0603_1608Metric_Pad0.98x0.95mm_HandSolder; LCSC C22787

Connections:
GND: R25.2, R28.2, R31.2; also elsewhere on the board
LED_GREEN: D5.2 (A); also elsewhere on the board
LED_RED: D3.2 (A); also elsewhere on the board
LED_YELLOW: D4.2 (A); also elsewhere on the board
unnamed: D3.1 (K), R25.1
unnamed: D4.1 (K), R28.1
unnamed: D5.1 (K), R31.1

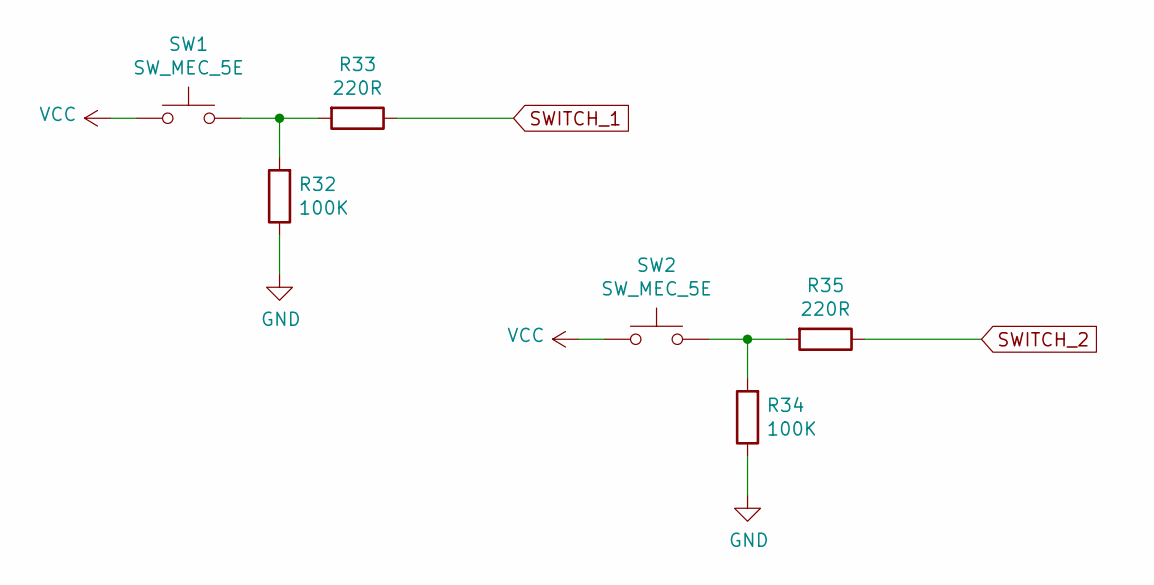
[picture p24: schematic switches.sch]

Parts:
R32, R34: 100K; R_0603_1608Metric_Pad0.98x0.95mm_HandSolder; LCSC C25803
R33, R35: 220R; R_0603_1608Metric_Pad0.98x0.95mm_HandSolder; LCSC C22962
SW1, SW2: SW_MEC_5E; SW_Push_1P1T_NO_CK_KSC6xxJ; LCSC C318889

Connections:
GND: R32.1, R34.1; also elsewhere on the board
unnamed: R32.2, R33.2, SW1.2
unnamed: R34.2, R35.2, SW2.2
SWITCH_1: R33.1; also elsewhere on the board
SWITCH_2: R35.1; also elsewhere on the board
VCC: SW1.1, SW2.1; also elsewhere on the board

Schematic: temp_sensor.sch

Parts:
R23: 100K; R_0603_1608Metric_Pad0.98x0.95mm_HandSolder; LCSC C25803
R24: NTC - 100k; R_0603_1608Metric_Pad0.98x0.95mm_HandSolder; LCSC C92368

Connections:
GND: R23.2; also elsewhere on the board
TEMP_SENSOR: R23.1, R24.2; also elsewhere on the board
VCC: R24.1; also elsewhere on the board

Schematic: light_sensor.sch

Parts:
D6: SMD3528C-50; LED_1210_3225Metric_Pad1.42x2.65mm_rotated; LCSC C242256
R26: 10K; R_0603_1608Metric_Pad0.98x0.95mm_HandSolder; LCSC C25804

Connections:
GND: R26.1; also elsewhere on the board
LIGHT_SENSOR: D6.1, R26.2; also elsewhere on the board
VCC: D6.2; also elsewhere on the board

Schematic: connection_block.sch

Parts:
J24: Conn_01x04_Female; PinSocket_1x04_P2.54mm_Vertical_centered; LCSC C124413
J25: Conn_01x05_Female; PinSocket_1x05_P2.54mm_Vertical_centered; LCSC C718240

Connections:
BUZZER: J25.2; also elsewhere on the board
DISPLAY: J25.1; also elsewhere on the board
LED_GREEN: J25.5; also elsewhere on the board
LED_RED: J25.3; also elsewhere on the board
LED_YELLOW: J25.4; also elsewhere on the board
LIGHT_SENSOR: J24.4; also elsewhere on the board
SWITCH_1: J24.1; also elsewhere on the board
SWITCH_2: J24.2; also elsewhere on the board
TEMP_SENSOR: J24.3; also elsewhere on the board

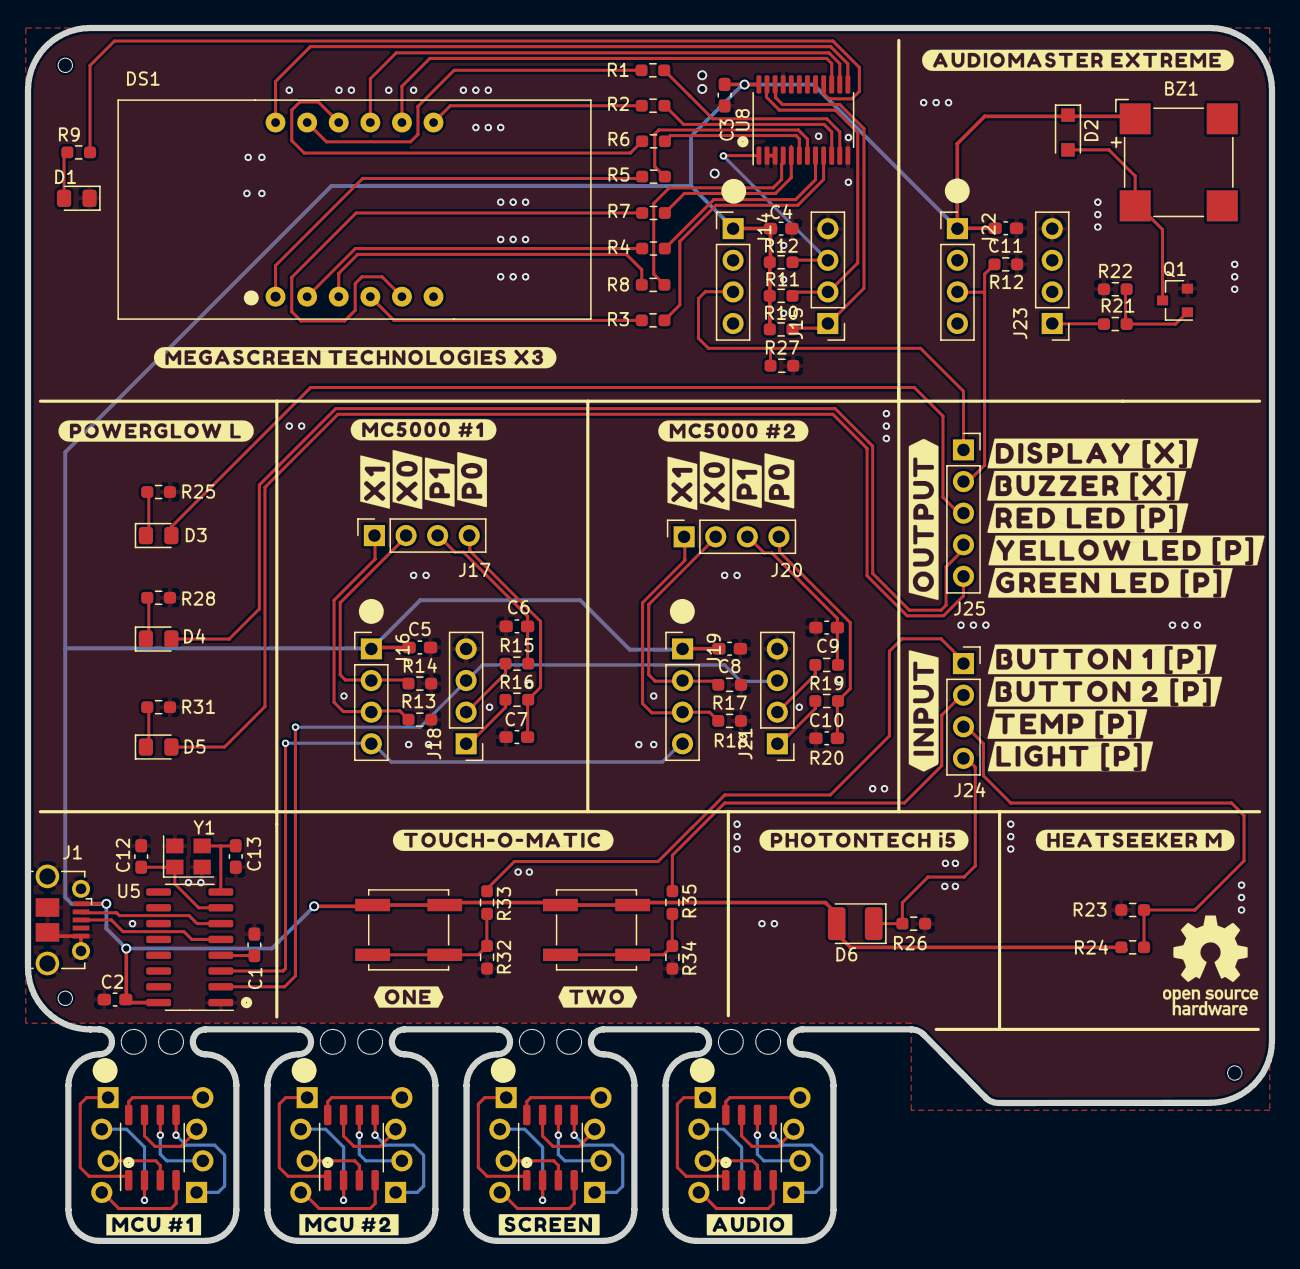
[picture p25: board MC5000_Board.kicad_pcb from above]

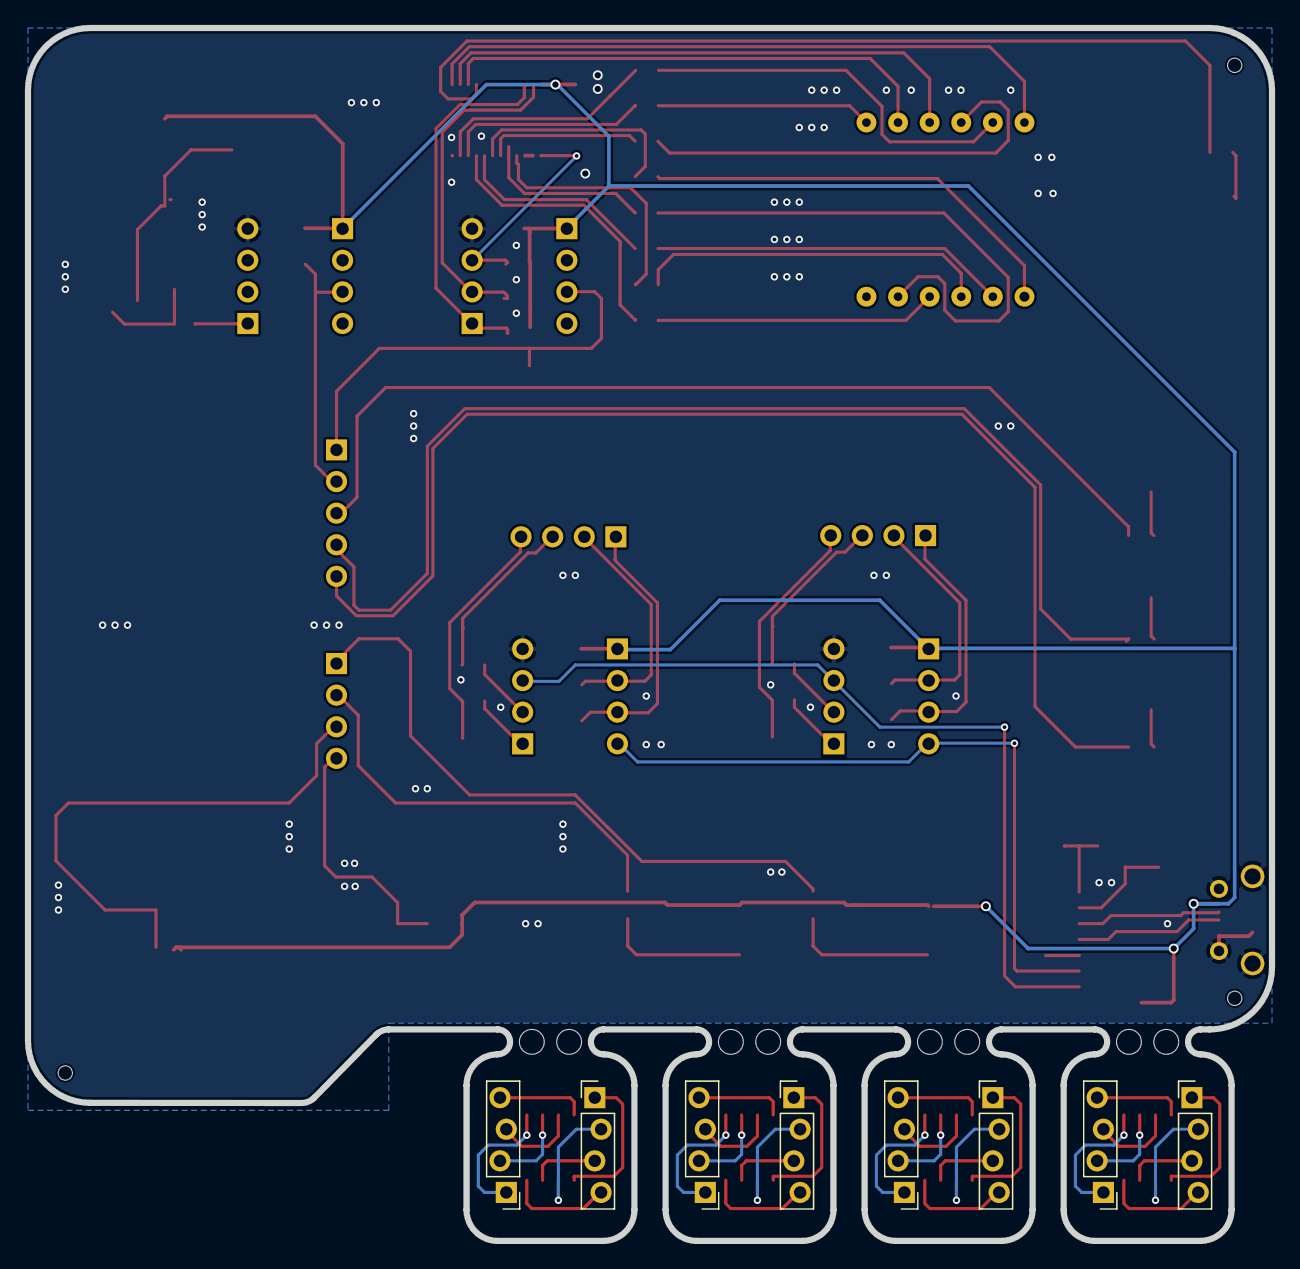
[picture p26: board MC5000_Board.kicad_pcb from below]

Board: 2 copper layers, 100.0 x 97.5 mm, 86 parts (8 on the bottom side), 94 nets.

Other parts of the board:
R12#2: 100K; R_0603_1608Metric_Pad0.98x0.95mm_HandSolder

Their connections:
unnamed 69: R12#2.1; also elsewhere on the board
VCC: R12#2.2; also elsewhere on the board

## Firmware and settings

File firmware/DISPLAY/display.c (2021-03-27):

#include <stdint.h>
#include "pfs173.h"
#include "pdkcommon.h"
#include "delay.h"
#include "xbus.h"

#define SDA_PIN 4
#define SCL_PIN 3
#define I2C_DELAY 0

const uint8_t segment_numbers[10] = {
    0x03,
    0x9F,
    0x25,
    0x0D,
    0x99,
    0x49,
    0x41,
    0x1F,
    0x01,
    0x09
};

int16_t xval;

uint8_t is_negative = 0;
uint8_t current_numbers[3] = {0,0,0};
uint16_t multiplex_counter = 0;
uint8_t digit = 0;

void interrupt_routine() __interrupt(0) {
        if (INTRQ & INTRQ_TM3) {  // TM3 interrupt request?
                CLOCK_TICK;
                INTRQ &= ~INTRQ_TM3;
        }
}

static void i2cByteOut(uint8_t b)
{
     for (uint8_t i=0; i<8; i++)
     {
         if (b & 0x80)
           __set1(PA, SDA_PIN); // set data line to 1
         else
           __set0(PA, SDA_PIN); // set data line to 0
         __set1(PA, SCL_PIN); // clock high (slave latches data)
         // sleep_us(I2C_DELAY);
         __set0(PA, SCL_PIN); // clock low
         b <<= 1;
     } // for i
     __set1(PA, SDA_PIN);
     __set1(PA, SCL_PIN);
     // sleep_us(I2C_DELAY);
     __set0(PA, SCL_PIN);
     // sleep_us(I2C_DELAY);
     __set0(PA, SDA_PIN);
} /* i2cByteOut() */

static void i2cStop() {
    __set0(PA, SDA_PIN); // data line low
    // sleep_us(I2C_DELAY);
    __set1(PA, SCL_PIN); // clock high
    // sleep_us(I2C_DELAY);
    __set1(PA, SDA_PIN); // data high
    // sleep_us(I2C_DELAY);
}

static void i2cBegin() {
   __set0(PA, SDA_PIN); // data line low first
   // sleep_us(I2C_DELAY);
   __set0(PA, SCL_PIN); // then clock line low is a START signal
} /* i2cBegin() */

int main(void) {
        // Set up padier register (can't be set seperately due to a hardware bug?)
        PADIER = (1U << XBUS0_PIN) | (1U << XBUS1_PIN);

        // Initialize hardware
        setup_xbus_hardware();

        // Set up I2C
        PAC |= (1 << SDA_PIN); // Set pin as output
        PAPH &= ~(1 << SDA_PIN); // Disable pullup
        __set1(PA, SDA_PIN); // Set pin high

        PAC |= (1 << SCL_PIN); // Set pin as output
        PAPH &= ~(1 << SCL_PIN); // Disable pullup
        __set1(PA, SCL_PIN); // Set pin high

        // Set up timer 3 for systick
        TM3C = TM3C_CLK_IHRC; // Use IHRC -> 8 Mhz
        TM3S = TM3S_PRESCALE_DIV16 | TM3S_SCALE_DIV4;
        TM3B = 180;
        INTEN |= INTEN_TM3; // Enable TM3 interrupt

        // Set multiplexer pins to output
        i2cBegin();
        i2cByteOut(0x40);
        i2cByteOut(6);
        i2cByteOut(0);
        i2cByteOut(0);
        i2cStop();

        INTRQ = 0;
        __engint();                 // Enable global interrupts

        // Main processing loop
        while (1) {

            // Multiplex display
            if (++multiplex_counter > 2000) {
                i2cBegin();
                i2cByteOut(0x40);
                i2cByteOut(2);
                i2cByteOut(segment_numbers[current_numbers[digit]]);
                i2cByteOut((0x01 << digit) | (is_negative ? 0x08 : 0x00));
                i2cStop();
                if (++digit > 2) {
                    digit = 0;
                }
                multiplex_counter = 0;
            }


            // Sleep if we need to
            if (clock_tick < sleep_until) {
                continue;
            }
            SLEEP(0);

            switch (xbus_handler()) {
                 case 1:
                    xval = get_x1_value();

                    if (xval < 0) {
                        is_negative = 1;
                        xval = -xval;
                    } else {
                        is_negative = 0;
                    }

                    current_numbers[0] = xval/100L;
                    current_numbers[1] = xval/10L - (current_numbers[0] * 10L);
                    current_numbers[2] = xval - (current_numbers[1]*10L + current_numbers[0]*100L);

                    break;
                 case 2:
                    get_x1_value();
                    break;
            }
        }
}

uint8_t _sdcc_external_startup(void) {
        EASY_PDK_INIT_SYSCLOCK_8MHZ();                                          //use 8MHz sysclock
        EASY_PDK_CALIBRATE_IHRC(8000000, 5000);                                  //tune SYSCLK to 8MHz @ 5.000V
        return 0;                                                               //perform normal initialization
}

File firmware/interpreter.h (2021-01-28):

#ifndef __INTERPRETER_H__
#define __INTERPRETER_H__

#include "easypdk/pdk.h"
#include "delay.h"
#include "serial.h"
#include "manchester.h"

#define INTERPRETER_CLOCK_TICK clock_tick++
#define GET_RI get_val(program[current_pos++], program[current_pos++])
#define GET_R program[current_pos++]
#define CHECK_CONDITION(x) if (command_condition != none && current_condition != command_condition) {current_pos += (uint8_t) x; break;}


#define SLEEP_TICKS 100

uint8_t *program;
uint8_t program_size = 0;
uint8_t current_pos = 0;
uint16_t ri_1;
uint16_t ri_2;
uint8_t reg;
int16_t xbus0_data = 0;
uint8_t xbus0_ticks = 0;
int16_t xbus1_data = 0;
uint8_t xbus1_ticks = 0;
uint8_t xbus_state = 0;
int16_t acc_register = 0;
int16_t dat_register = 0;
volatile uint16_t clock_tick = 0;
uint16_t sleep_until = 0;

typedef enum {
        none=0,
        true=1,
        false=2
} true_or_false;

true_or_false current_condition;

#define NUM_COMMANDS 19 // MAX 31!
const uint8_t commands[NUM_COMMANDS] = {
        0x0,   // failure
        0x01 << 2,   // nop
        0x02 << 2,   // mov R/I R
        0x03 << 2,   // jmp L
        0x04 << 2,   // slp R/I
        0x05 << 2,   // slx P
        0x06 << 2,   // teq R/I R/I
        0x07 << 2,   // tgt R/I R/I
        0x08 << 2,   // tlt R/I R/I
        0x09 << 2,   // tcp R/I R/I
        0x0A << 2,   // add R/I
        0x0B << 2,   // sub R/I
        0x0C << 2,   // mul R/I
        0x0D << 2,   // not
        0x0E << 2,   // dgt R/I
        0x0F << 2,   // dst R/I R/I
        0x10 << 2,   // label L
};

#define P0_PIN 3
#define P0_ADC ADCC_CH_AD8_PA3
#define P0_PWM PWMG2C
#define P0_PWM_ENABLE PWMG2C_OUT_PA3
#define P0_PWM_DUTY_H PWMG0DTH
#define P0_PWM_DUTY_L PWMG0DTL

#define P1_PIN 4
#define P1_ADC ADCC_CH_AD9_PA4
#define P1_PWM PWMG1C
#define P1_PWM_ENABLE PWMG1C_OUT_PA4
#define P1_PWM_DUTY_H PWMG1DTH
#define P1_PWM_DUTY_L PWMG1DTL

#define X0_PIN 5

#define X1_PIN 6

uint8_t get_p0_value() {
    P0_PWM &= ~P0_PWM_ENABLE; // Disable PWM output on pin
    PAC &= ~(1 << P0_PIN);      // Enable P0 Pin as input
    ADCC = P0_ADC;                             // Set ADC for pin
    ADCC |= ADCC_ADC_ENABLE;                    // Enable ADC
    delay_us(400);                              // wait to settle
    ADCC |= ADCC_ADC_CONV_START;                //start ADC conversion
    while( !(ADCC & ADCC_ADC_CONV_COMPLETE) );  //busy wait for ADC conversion to finish (we also could use the ADC interrupt...)
    return ADCR;
}

void set_p0_value(uint8_t val) {
    ADCC = 0;
    PAC |= (1 << P0_PIN);    // Enable P0 Pin as output
    P0_PWM |= P0_PWM_ENABLE; // Enable PWN output on Pin
    P0_PWM_DUTY_H = val;
    P0_PWM_DUTY_L = 0;
}

uint8_t get_p1_value() {
    P1_PWM &= ~P1_PWM_ENABLE; // Disable PWM output on pin
    PAC |= (1 << P1_PIN);      // Enable P1 Pin as input
    ADCC = P1_ADC;                             // Set ADC for pin
    ADCC |= ADCC_ADC_ENABLE;                    // Enable ADC
    delay_us(400);                                // wait to settle
    ADCC |= ADCC_ADC_CONV_START;                //start ADC conversion
    while( !(ADCC & ADCC_ADC_CONV_COMPLETE) );  //busy wait for ADC conversion to finish (we also could use the ADC interrupt...)
    return ADCR;
}

void set_p1_value(uint8_t val) {
    if (!(PAC & (1 << P1_PIN))) {
        ADCC = 0;
        PAC |= (1 << P1_PIN);    // Enable P0 Pin as output
        P1_PWM |= P1_PWM_ENABLE; // Enable PWN output on Pin
    }
    P1_PWM_DUTY_H = val;
    P1_PWM_DUTY_L = 0;
}

void get_x0_value() {
    PAC &= ~(1 << X0_PIN);      // Enable X0 Pin as input
    PADIER |= (1 << X0_PIN);    // Enable digital input on X0
    xbus0_data = 0x4000;
    xbus0_ticks = 255;
}

void set_x0_value(uint16_t val) {
    PAC |= (1 << X0_PIN);       // Enable X0 Pin as output
    PADIER &= ~(1 << X0_PIN);   // Disable digital input on X0
    // fill up buffer and mark buffer as a send buffer by setting bit0
    // buffer will be sent in interpreter loop
    xbus0_data = val & 0x8000;
    xbus0_ticks = 255;
}

void get_x1_value() {
    PAC &= ~(1 << X1_PIN);      // Enable X1 Pin as input
    PADIER |= (1 << X1_PIN);    // Enable digital input on X0
    // clear buffer and mark it as a receive buffer by setting bit1
    // buffer will be received in interpreter loop
    xbus1_data = 0x4000;
    xbus1_ticks = 255;
}

void set_x1_value(uint16_t val) {
    PAC |= (1 << X1_PIN);       // Enable X1 Pin as output
    PADIER &= ~(1 << X1_PIN);   // Disable digital input on X1
    // fill up buffer and mark buffer as a send buffer by setting bit0
    // buffer will be sent in interpreter loop
    xbus1_data = val & 0x8000;
    xbus1_ticks = 255;
}


void setup_interpreter_hardware() {
    PAC &= ~(1 << P0_PIN);     // Enable P0 Pin as input
    PAPH &= ~(1 << P0_PIN);    // Disable P0 pullup

    PAC &= ~(1 << P1_PIN);     // Enable P1 Pin as input
    PAPH &= ~(1 << P1_PIN);    // Disable P1 pullup

    PAC &= ~(1 << X0_PIN);      // Enable X0 Pin as input
    PAPH &= ~(1 << X0_PIN);    // Disable X0 pullup

    PAC &= ~(1 << X1_PIN);     // Enable X1 Pin as input
    PAPH &= ~(1 << P1_PIN);    // Disable P1 pullup

    ADCRGC = ADCRG_ADC_REF_VDD;                // VCC reference for ADC
    ADCM = ADCM_CLK_SYSCLK_DIV16;             // ADC divider 16

    // Enable PWMG1 and PWMG2 for p port output
    PWMGCLK = PWMGCLK_PWMG_ENABLE;
    PWMG1C = PWMG1C_ENABLE;
    PWMG2C = PWMG2C_ENABLE;
    PWMGCUBL = 0x00;
    PWMGCUBH = 0x80;
}

void handle_interpreter_status_request(uint8_t * ret) {
        ret[0] = acc_register+1000 >> 8;
        ret[1] = acc_register+1000 & 0xFF;
        ret[2] = dat_register+1000 >> 8;
        ret[3] = dat_register+1000 & 0xFF;
}

void reset_program() {
        // Reset registers and outputs
        current_pos = 0;
        clock_tick = 0;
        acc_register = 0;
        dat_register = 0;
        current_condition = none;
        xbus0_data = 0;
        xbus1_data = 0;
        xbus_state = 0;
        sleep_until = 0;
        set_p0_value(0);
        set_p1_value(0);
}

void set_program(uint8_t *new_program, uint8_t new_program_size) {
        program = new_program;
        program_size = new_program_size;
}

uint8_t find_label(uint8_t label) {
    for (uint8_t i = 0; i < program_size-1; i++) {
        uint8_t command = program[i] & 0xFC;
        if (command == 16) {
                if (program[i+1] == label) return i+2;
        }
    }
    return 0;
}
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

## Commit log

2021-02-09 Added serial connect button
2021-02-21 Added kicad gitignore
2021-02-21 Added pcb
    [MC5000_Board.kicad_pcb, MC5000_Board.sch, PFS172_breakout.sch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]
2021-02-23 Work on PCB
    [MC5000_Board.kicad_pcb, MC5000_Board.sch, MCU5000.sch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]
2021-02-23 tuned pwm frequency
2021-02-23 Nice labels
    [MC5000_Board.kicad_pcb, MCU5000.sch]
2021-02-24 Added buzzer
    [100K_NTC.sch, MC5000_Board.kicad_pcb, MC5000_Board.sch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]
2021-02-24 Added LEDs
    [MC5000_Board.kicad_pcb, MC5000_Board.sch, MCU5000.sch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]
2021-02-25 Cleanup libs
    [LEDs.sch, MC5000_Board.kicad_pcb, MCU5000.sch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]
2021-02-25 Added label for buzzer
    [MC5000_Board.kicad_pcb]
2021-02-25 Added switches
    [LEDs.sch, MC5000_Board.kicad_pcb, MC5000_Board.sch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]
2021-02-25 changed pcb file structure
    [100K_NTC.sch, LEDs.sch, MC5000_Board.kicad_pcb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]
2021-02-26 finished pcb
    [LEDs.sch, MC5000_Board.kicad_pcb, MC5000_Board.sch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]
2021-02-26 Fixed 3D models
    [MC5000_Board.kicad_pcb]
2021-02-26 Connected LEDs to GND
    [LEDs.sch, MC5000_Board.kicad_pcb]
2021-03-10 XBus changes; PCB changes
    [LEDs.sch, MC5000_Board.kicad_pcb, MCU5000.sch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]
2021-03-11 Production board
    [LEDs.sch, MC5000_Board.kicad_pcb, MC5000_Board.sch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]
2021-03-11 Removed fab files
    [MC5000_Board-B_Cu.gbr, MC5000_Board-B_Mask.gbr, MC5000_Board-B_Paste.gbr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]
2021-03-11 Fixed USB footprint
    [MC5000_Board.kicad_pcb]
2021-03-13 added board with breakouts
    [100K_NTC.sch, LEDs.sch, MC5000_Board.kicad_pcb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]
2021-03-13 One PCB to rule them all
    [100K_NTC.sch, LEDs.sch, MC5000_Board.kicad_pcb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]
2021-03-13 Fabrication stuff
    [MC5000_Board.kicad_pcb, MCU5000.sch, PFS172_breakout.sch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]
2021-03-14 Footprint changes
    [MC5000_Board.kicad_pcb, MCU5000.sch, PFS172_breakout.sch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]
2021-03-15 Changed USB<->Serial to CH340G
    [MC5000_Board.kicad_pcb, USB_serial.sch, display.sch]
2021-03-15 Added NOCONNECTION flags
    [display.sch]
2021-03-17 Added arm deployment
2021-03-18 Changed connectors
    [MC5000_Board.kicad_pcb, MCU5000.sch, buzzer.sch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]
2021-03-21 check kicad and make docs on push
2021-03-21 Design changes
    [MC5000_Board.kicad_pcb, buzzer.sch]
2021-03-21 Changed overview schematic
    [MC5000_Board.kicad_pcb, MC5000_Board.sch]
2021-03-21 Uodate pcb docs
2021-03-21 Update pcb docs
2021-03-26 Added OSHW logo
    [MC5000_Board.kicad_pcb]
2021-03-26 Modified silkscreen
    [MC5000_Board.kicad_pcb]
2021-04-08 Changed display LED color
    [LEDs.sch, MC5000_Board.kicad_pcb, display.sch]
2021-04-08 Made plug footprint tighter
    [MC5000_Board.kicad_pcb]
2021-04-15 Changed USB port footprint
    [MC5000_Board.kicad_pcb]
